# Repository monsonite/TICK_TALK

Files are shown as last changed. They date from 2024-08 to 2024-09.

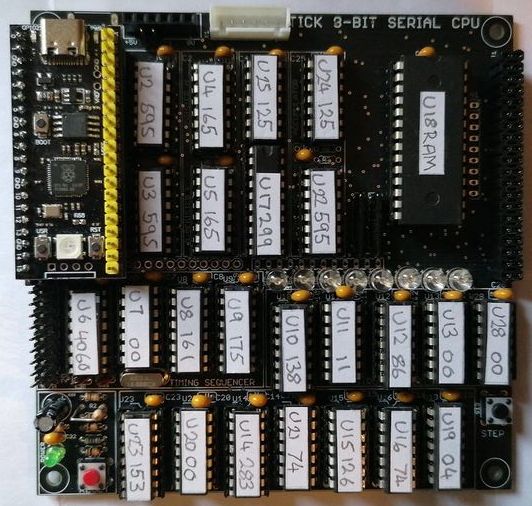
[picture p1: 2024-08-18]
Tick_Aug_17th.jpg

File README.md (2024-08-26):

# TICK_TALK
## An experimental 8-bit, bit serial computer.

## Hebden Bridge Workshop Update  25-08-24

OSHCamp 2024

TICK Workshop Update.

Thanks to the 16 people who attended the 1st TICK workshop session at Hebden Bridge, on Sunday August 25th.

Most kits were assembled without too many problems, and several were close to completion at the end of the afternoon.

Unfortunately some components were misplaced and not found until late in the afternoon, close to packing up time, but workarounds were employed.

Attendees should make contact me via email at k*n.boat@gmail.com - replacing the "t" with the 1st letter of my 1st name.

### Points Arising.

1.  The 74HC4060.dig file is now available. Download it and place it in the Lib  (libraries) folder of where you have installed "Digital"  - ideally under 

\Digital\Digital\lib\DIL Chips\74xx\counter

Then restart Digital and select components, custom, update and it should then be available.

2. Tick now has a Hackaday.io project page here:

https://hackaday.io/project/197333-tick-a-novel-homebrew-mcu-architecture-in-28-ics

Please feel free to join the project team and message me in the team messaging section.

3. It would be sensible to convert the Eagle CAD pcb schematic and pcb layout files to KiCad - to allow greater accessibility to interested users. I will investigate importing the schematic into Kicad, with the aim of generating the next iteration of the pcb using Kicad.

4. As the workshop was primarily focussed on assembly of the pcb in the time available, the Pi Pico firmware aspects of the project remained virtually unmentioned.

The principal role of the Pico is to emulate a 64K x16-bit ROM. It does this by "sniffing" the ROM address lines generated from the Program Counter, and using the two 74HC595 shift registers (U26, U27) located under the Pi Pico, to output the 16-bit value from that ROM address onto the Instruction Bus.

5. The 6-way JST cables supplied will allow the Pi Pico access to both the ROMulator Port X2 (on the left) and the SPI Port X1 (on the right). Details of these connectors and the modifications to the wiring of the cable to the Pico GPIO pins 18 to 21 and 26 to 29 will be released shortly in a separate document'

6.  I have received notification from PCBWay in China and they are prepared to sponsor the manufacture of the next version of the Tick PCB.

I am tempted to have a SMT version assembled in China - so it will be smaller, lighter and have better features.

I would like your feedback over, whether you would like to receive this SMT version in the Autumn.

Please send feedback to my Gmail address.

Ken

Update  - Lissa has created a new discord server for TICK

try this invite code.

https://discord.gg/FmW9dqFGb5

/*************************************************************************************************************************



TICK is an experimental 8-bit, serial arithmetic CPU designed around the commonly available 74HCxx logic series.

TICK uses 26 74HXxx ICs, plus a 32K byte RAM and a 64K x 16-bit ROM - or a ROM emulator.

TICK fits onto a 4-layer PCB, sized just 110mm x 110mm. It has 5 principal connectors that allow you to access all of the main signals and buses. Low cost 6-way JST XH ribbon cables are used to hook up the TICK serial interface bus and the Pi Pico SPI.  A 40 way 2.54mm pitch header allows access to the parallel buses.

USB (power) is supplied either through a USB microB connector or via USB C connector of the the Clone Pi Pico "ROMulator".

PCB Headers are included that will allow a very low-cost Raspberry Pi Pico (clone) to be plugged in, providing emulation of the ROM and also implementing a simple serial interface to a laptop or PC.

TICK has evolved slowly over several months, and this repo reflects the most recent design files, manufacturing data and BOM. The earlier repo "TICK" is purely reserved for earlier work. All current and future developments will be documented here.

TICK started life a few months ago and is highly influenced by the the developments I did on "MITE" its 16-bit Cousin. Here the basics of the timing pulse generator and ALU were thashed out to the point that I am happy to utilise them in a new design.

Much of the combinational logic has been rationalised, and short of implementing the ALU and control logic in a ROM, I believe that I have reached a point where the logic is stable, and not reduced to a blackbox ROM.

TICK is 26 74HCxx ICs plus a ROM and RAM.

The ICs are utilised in 5 main sub-circuits:

1. Clock Sequencer and Timing Pulse Generator.

2. Instruction Decoder

3. ALU and PC Incrementer, plus Jump logic.

4. Memory Control Hardware.

5. GPIO and ROMulator interfaces.

In an ideal world,  TICK would be a BlackBox with just 2 wires for power, and 2 wires for data in and data out. If you look at a landline telephone or broadband modem, they only have 2 wires or 4 wires. However for the purposes of this project we reqire syncronous data transfer - and that needs a clock that is shared between all nodes.

In general terms, TICK communicates with external devices via an SPI compatible interface.

## Architecture

TICK is highly influenced by Marcel van Kervinck's 8-bit Gigatron TTL Computer. The Gigatron used ten ICs in its ALU, I can do it serially in two. However a bit-serial design needs additional ICs to implement the clock sequencer, the timing pulse generator and the SRAM and Jump logic.

It is very marginal whether an 8-bit serial architecture will have fewer ICs than an 8-bit parallel design. Bit Serial really comes into fruition when you have a wordsize of 16 or more bits.

So the motivation for developing TICK was to make an intelligent node that can interface to SPI serial peripherals and other intelligent nodes. It won't be the fastest computer on the planet - but it should be able to compete with 1970s/80s 8-bit workhorses, like the 6502, Z80, 8051, 6309 etcand even older machines that predate the microprocessor - such as the  PDP-8 (1965) and the EDUC8 (1974).

TICK is a modified Harvard architecture.  Address and data from the ROM are conveyed on separate buses to those of the RAM. Simple shift registers are used to convert between the serial and parallel domains. A task that they can do very efficiently.

### Registers

TICK has a single 8-bit accumulator AC. AC may be loaded with an 8-bit literal direct from the lower 8 ROM data lines, or AC can be loaded with data addressed from the 32K x 8-bit SRAM.

As well as the Accumulator AC, TICK has a 16-bit wide general purpose register known as the B-Register. The B-Reg is 16-bits wide, in order to accept a 16-bit word, in parallel from the ROM and either use that as a indirect RAM address, or load it into the ROM Program Counter (PC) to perform a Conditional Branch or a 16-bit Long Jump.

The PC mentioned above is also 16-bits wide and can cover the full 16 bits of the ROM addressing range. A 16-bit jump is non-conditional, but an 8-bit "page" branch is conditional on the ZERO and SIGN flags from the Accumulator.

## Circuit Description (Draft 20-08-24)

Tick is an experimental, 8-bit, bit serial computer designed to interface to SPI peripherals and memory.

It has a 16-bit Program Counter, a 16-bit B-Register, an 8-bit Accumulator and an 8-bit Input Register.

The circuit may be subdivided into several sub-sections for easier analysis.

1. Clock Sequencer and Timing Pulse Generator (TPG)
2. Instruction Decoder
3. Program Counter (PC)
4. Arithmetic and Logic Unit (ALU)
5. Conditional Branch Logic
6. Memory Access
7. Input/Output  (I/O)
8. ROM Emulation

## 1. Clock Sequencer and Timing Pulse Generator (TPG)

This is at the heart of the design and co-ordinates all of the control signals.

A 14-bit binary counter U6 (74HC4060) provides a crystal oscillator with a 16MHz crystal Q1. This is divided down to provide 10, link selectable clock outputs from 1Khz (approx) to 1MHz. The selected clock feeds a 4-bit counter, U8 (74HC161) and this is used to generate a burst of 16 clock pulses for the Program Counter (PC-CLK) and 8 gated clock pulses (GCLK) for the 8-bit shift registers. A SR latch formed around NAND U7 (74HC00) with triple input AND U11 (74HC11) provides a means of gating the clock to generate PC-CLK and GCLK.

The terminal count of the 74HC161 (RCO) is used to feed a chain of 4, D-type flipflops U9 (74HC175), and these "top and tail" pulses T0, T1, T17 T18 and their complements are used to synchronise the loading of shift registers andread/write access to the SRAM.

A power-on reset circuit is formed around U19A and U19B. This resets all shift registers and counters when power is applied to the circuit. There is also a RESET switch S13, which allows a manual reset to be performed.

## 2. Instruction Decoder

The instruction from the ROM is 16-bits wide and consists od an instruction field IR7:0 and a data field P7:P0.

The instruction field is further divided into a 4-bit operand  IR7:IR4, and a condition field IR3:IR0.

If IR7=0, the remainder of the 16-bit word is treated as a literal and is loaded into the B-Register.

If IR7=1, this indicates a RAM memory reference instruction with IR6:4 defining the operation, and the remainder of the instruction word IR3:0 and P7:0 treated as a 12-bit address which is output onto the RAM address bus MA11:MA0.

Instruction decoding is done with 4 or 5 "basic gate" ICs. As entirely combinational logic, it could also be implemented in a small ROM, or even with a diode matrix.

Instruction decoding begins with U10 (74HC138) a 3 to 8 line decoder, which performs the primary stage of decoding. 

Here the instruction field IR6:4 is decoded into the 8 instruction groups, with one of its "Y" outputs being set low for each individual instruction group - as follows.

/Y0		LOAD
/Y1		AND
/Y2		XOR
/Y3		OR
/Y4		ADD
/Y5		SUB
/Y6		STORE
/Y7		JUMP

These low going outputs are further combined in logic U11, (74HC11), U12 (74HC86) and U13 (74HC00) to provide a series of control signals, time selected by the timing pulses T0, T1, T17 and T18.

Quad 2-input NAND gate U13 does the bulk of the secondary decoding, where instruction groups /Y0 to /Y7 are gated with timeslot pulses. 

The two XOR gates U12B and U12C have one input tied high and thus act as simple inverters. U12A is also an inverter and is connectedas an 8-input wired OR gate with 8 input diodes and a pull-down resistor, used to detect when the output of the Accumulator or memory on the data bus is equal to zero.

U11 is a triple 3-input AND. U11A detects if any of the Boolean instructions have been selected (/Y1, /Y2, /Y3) and is used to suppress the carry.

## 3. Program Counter.

This is a 16-bit counter and consists of two 74HC595 serial in parallel out (SIPO) shift registers U2 and U3 connected in series. As a bit serial computer, it is reasonable to use shift registers and a half adder to create a Program Counter, especially as it can be loaded from a serial data stream.

The registers convert a serial bitstream into a parallel address, which is used to address the 64K x 16-bit ROM (U1 AT27C1024). For development purposes, the ROM is replaced with a Pi Pico clone, for a more efficient development cycle.

The 74HC595 is a SIPO shift register, with all outputs connected to an octal tristate latch. Once the shift register contains the required address, this can then be latched onto the output pins, where it will remain for the whole duration of the machine cycle. In this respect, the PC "freezes" the address and as such acts as the Instruction Register, holding the Instruction for the complete Fetch, Execute, Writeback cycle. As the lower 12-bits of the ROM contain the effective memory address (EA), the address of the operand read, will be retained for the writeback operation.

A Program Counter has two modes of operation, either to increment the ROM address by 1 at the end of each machine cycle, or to load the shift registers from an external serial source to allow a jump to be executed. 

The PC increment hardware is based around a half adder, followed by a 2-input multiplexer. The mux chooses between the increment mode and the load (jump) mode.

The PC half adder is provided by one half of a 4-bit full adder (74HC283 U14). The multiplexer is one half of a 74HC126, quad tristate buffer (U15). The other halves of U14 and U15 are used in the ALU, so not wasted. Instruction group 7 "Jump" is used to swich the PC multiplexer between its +1 increment mode and the jump mode, where it is loaded with data from the B-Register, which has been loaded from the ROM or from and external source.

## 4. Arithmetic and Logic Unit (ALU)

The ALU is based around a full adder, in this case provided by U14 (74HC283) four bit adder that has been partitioned to provide a half adder for the Program Counter and a full adder for the ALU. The full adder can perform subtraction too, by inverting the input from the B-register and adding 1, by way of the Carry input.

The full adder provides sum (XOR) and carry (AND) outputs, which are selected using a 2-input multiplexer, provided by U15 (74HC126). This allows the ZERO, AND, XOR and OR bitwise Boolean logic functions to be selected by way of two instruction control lines I0 and I1. If a Boolean function is selected, the carry propagation from bit to bit is suppressed.

## 5. Conditional Branch Logic

During a conditional branch, the 4-bit instruction field IR3:0 defines the condition as follows by testing the ZERO flag and the MSB of the Accumulator:

0000		Long Jump
0001		AC > 0  	BGT
0010		AC < 0		BLT
0011		AC != 0		BNE
0100		AC = 0		BEQ
0101		AC >= 0		BGE
0110		AC <= 0		BLE
0111		Branch Always
1xxx		
  
A 4 input multiplexer, U23 (74HC153) receives the condition field IR2:0 on inputs C2:C0. The JUMP signal is used to enable the multiplexer via pin 1.

The ALU status bits ZERO and SIGN (BUS7), are applied to select inputs A and B. If a condition is met the BCC output on pin 7 is raised.

The other half of the multiplexer is not used.

The BCC output is combined in NAND U28 (74HC00) to provide a LONGJUMP control signal if IR3 = 0. If IR3 = 0 the jump address is taken from the 11 lower bits of the instruction word, limiting it to 0 to 2047 in RAM.

## 6. Memory Access.

The 32K byte RAM U18 (62256) is read onto the data bus during timeslot T0, and written back to during timeslot T18.

The address for the RAM comes from the full 16-bit output of the Instruction ROM but with the exception that IR7=1, so a range of 32768 addresses may be reached.

There are 2 distinct forms of Load instruction:

IR7=1 Memory Reference Instruction 

IR3:IR2 and P7:0 forms a 12-bit address for the A operand to place in the Accumulator. This applies to LOAD, AND, XOR, AND, ADD, SUB and STORE instructions.

IR7=0.

Load Accumulator with data from address IR7:0 and P7:0 thus covering addresses 0 to 32767, which is the full extent of the fitted RAM.

Load the B-Register with the 15 bit constant, IR6:0 and P7:0

## 7. Input/Output  (I/O)

TICK is intended to work with SPI peripherals and memory. As such it implements a basic SPI bus with MOSI, MISO, SCLK and /SS signals.

The serial output of the Accumulator U17 (74HC299) is fed through a tristate buffer U24A and sends this MOSI signal to connector X1 pin 2. The MISO signal is received by U22 (74HC595) 8-bit tristate, latchable shift register on X1 pin 3 and can be gated onto the 8-bit data bus. The serial clock X1 pin 4 is just the 8 cycle gated clock burst, GCLK. The slave select /SS or /CE (chip enable) is the inverted output Q4 of the gating counter U8 (74HC161). A maximum SCLK of 1MHz can be achieved from the current 16MHz clock crystal oscillator.

## 8. ROM Emulator and SPI Peripherals.

Whilst TICK was designed to have firmware coded into a 64K x 16-bit ROM, U1 (AT27C1024) it makes sense to emulate the ROM with a small microcontroller - in this case a low cost clone of the popular Raspberry Pi Pico module.

The Pico plugs into 2 x 20 way female pcb socket J3 on the left hand edge of the pcb.  It's GPIO lines 0 to 15, "sniff" the ROM address generated by the Program Counter, and then look up the associated instruction word from a table of ROM contents held in the flash memory of the Pico. This 16-bit word is then output to a pair of 74HC595 shift registers, U26 and U27 located below the Pico module, which present the "ROM" data to the relevant ROM data lines IR7:0 and P7:0.

The Pi Pico provides regulated 3V3 supply for the TICK board and also a USB serial port for debugging. Unused GPIO, ADC chanels and other resources on the Pico can be used to support the TICK board. The Pico can act as a smart serial peripheral and connect to the TICK via the SPI port connector X1.

Xpansion Ports, X1, X2 - Connector Pin-Outs

### X2  (left to right) ROMulator Port

Used to emulate a 64K x 16-bit ROM and provide serial port access to laptop.

1   3V3          Connects to VCC to power the Tick PCB

2   /PC_EN       Set low to eneable the Program counter

3   SER_IN       Serial data from Pi Pico to shift registers U26 and U27

4   SER_CLK      Clock from Pi Pico to synchronise the serial data packets and clock U26 and U27

5   STB          A strobe pulse at the end of the data packet that latches the data onto the Instruction Bus

6   0V           Connects to GND plane (0V) of Tick pcb

### X1  (left to right) SPI Port

Used to connect the Tick CPU to SPI peripherals or use the Pi Pico as a smart peripheral.

1   3V3          Connects to VCC to power the Tick PCB

2   MOSI         8-bit Serial data output from Tick Accumulator to PI Pico MISO

3   MISO         8-bit Serial data output from PI Pico MOSI to Tick input register U22 (74HC595).

4   GCLK         Gated clock burst generated by Tick to synchronise serial data transfer

5   /SS          Slave Select - signal goes low for the duration of the GCLK burst. Used to latch data into the SPI slave device

6   0V           Connects to GND plane (0V) of Tick pcb

Two 6-way JST cables are used to connect X1 and X2 to the GPIO and 3V3 supply from the Pi Pico. These need to have a couple of wires swapped  to form the following connections:

### X2 - ROMulator Port 

1       Pico 3V3

2       Pico 29  /PC_EN

3       Pico 28  Serial Data

4       Pico 27  Serial Clock

5       Pico 26  Latch data

6       Pico GND

### X1 - SPI Port 

1       Pico 3V3

2       Pico 19  Pico SPI 0 MISO

3       Pico 16  Pico SPI 0 MOSI

4       Pico 18  GCLK

5       Pico 17  /SS 

6       Pico GND

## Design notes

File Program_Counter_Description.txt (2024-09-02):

Program Counter.

The Program Counter consists of a 16-bit serial-in, parallel out shift register, a half adder, an 2-input multiplexer and a carry flipflop. However the design is somewhat convoluted and spread across 6 ICs.

The following notes explain the design, and a simulation of the Program Counter circuit is available on the github repo.

U2 and U3 (74HC595) form the 16-bit Program Counter.

Output pins

15		RMA15 (MSB)
1		RMA14
2		RMA13
3		RMA12
4		RMA11
5		RMA10
6		RMA9
7		RMA8  (LSB)

9		Serial Output to lower stage
10		/CLR	Active LOW reset signal - check it goes low when RESET switch pressed
11		PC_CLK  16-clock pulse burst - check for continuous clocking
12		Outout Latch clock pulse - low going pulse, every 16th clock
13      /PC_EN  Active LOW enable pin - should remain LOW
14      PC_IN  Serial Input 

8		GND
16 		3V3

The Program Counter is connected to U12, U14 U15 and U16.

U12 (74HC86) provides inversion of the !JMP signal.

The left hand side of U14 (74HC283) provides a half adder to increment the PC by one, once per machine cycle (20 clocks).

The right hand side of  U15 (74HC126) provides a 2-input multiplexer. The PC is either loaded with the current count, or if !JMP is LOW it is loaded with the value in the B-Register.

U16 (74HC74) is a dual flipflop. The right-hand flipflop is used to hold any carry produced when adding 1 to the PC and adding it into the next half sum.

Ensure continuity of:

U2 (14) to U15 (8,11) 	*
U2 (9) to U3 (14)  		*
U3 (9) to U14(6) 		*

U16 (12) to U14(1)		*
U16 (11) to U7 (8)		new
U16 (10) to U9(11)		new
U16 (9) to U14(7)		*
 
U14 (4) to U15(9)		*

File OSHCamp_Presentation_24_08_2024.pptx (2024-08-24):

## Revisiting the Bit-Serial Computer Architecture

A Practical Guide to Bit Serial Computing

Ken Boak
OSHCamp, 24th August 2024

## Introduction

In the late 1980s, the late, great author and futurologist, Richard Adams made a series of radio documentaries, and a book “Last Chance to See” documenting his travels around the world to seek out and document various animal species that were on the brink of extinction, including the Komodo Dragon, the Kakapo of New Zealand and the Aye-Aye lemur of Madagascar.

In a lesser capacity, I have spent the last 5 years exploring simple computer architectures, based on what are often colloquially known as “TTL” chips, but more correctly 74HC series of logic devices.
With successive generations of logic, these devices have 60+ years or heritage, and are based on high-speed CMOS logic, FETs and transmission gates, and no longer bipolar, multi-emitter transistors, but have retained their pin compatibility with the older series.

However, these devices are slowly being obsoleted, resulting in a smaller range, fewer packaging options and decreased availability. Basically the slow erosion and ultimate extinction of the species.

I realised that the window of opportunity to build a working “TTL Computer” was rapidly diminishing, and so after 4 years of procrastination, I began my journey, for proper, earlier this year.
To add a little novelty to my design, I chose to use the little known technique of Bit Serial Arithmetic.

## Until 1960, almost all computers used bit-serial arithmetic

- Uses considerably fewer vacuum tubes or transistors than parallel
- It only had to process a pair of bits at a time
- It simplified hardware making it practical and mostly affordable
- Easily extended to longer word sizes with no linear scaling in hardware
- The trade off, was it was relatively slow. EDSAC (1949) managed 600 operations per second, on 17-bit words.
- With 74HCxx logic we can achieve 50,000 8-bit additions per second.

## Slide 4

- In this presentation I will discuss the techniques and practical hardware required for bit-serial computation.
- Commencing with the basic full adder circuit, I show how it is applied to bit serial addition and subtraction and then extend it to provide the common logic functions AND, OR, XOR and ZERO. It may also provide one’s complement invertion, and two’s complement negation. Increment and Decrement are also possible with simple extensions to the control of the ALU.
- As well as the ALU, shift registers are the fundamental storage device for bit-serial computer architectures. I summarise the basic types, their function and use and give examples available cheaply in 74HCxx High Speed series logic.
- Shift registers can also perform operations such as shift, rotate and nybble or byte swap.
- The discussion concludes with an illustration of how a small, experimental 8-bit, bit-serial computer can be built up from common 74HC series parts.
- This is the theme of tomorrow’s Workshop Build session: your own bit-serial machine.

## 1 plus 1 is 10……. 1 and 1 is 1 ……..

- The principle is very simple – it’s just like basic addition that we all learned in primary school, except that it is in binary.
- We start with the units on the right, and if there is a carry, we make a mental note and bring it to the next column to the left.
- For binary, the process is almost identical. Starting with the least significant bits, A0 and B0, we add them together. If a carry is generated, we store it in a flipflop so that it can be added into the next addition, A1 plus B1.
- We repeat this bit operation until we have completed the whole word.
- To do this in logic we need a pair of shift registers to feed the serialised data into a full adder. The full adder produces the SUM term from A XOR B and carry from the A AND B function. This produces a half add, which is then repeated to include any carry input from the previous stage.
- In total we require just two XOR gates and 3 NAND gates, plus a flipflop to hold the inter-stage carry.

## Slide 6

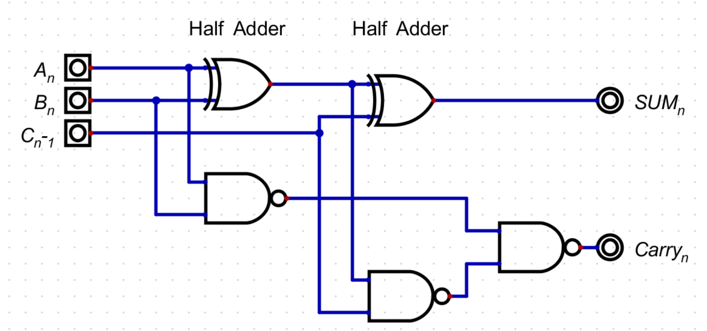
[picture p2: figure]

A Full Adder made from basic gates.

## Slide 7

A typical serial adder.

It uses two shift registers A3:A0 and B3:B0. Shift register A is normally called the Accumulator. It can be parallel loaded from a bus, or serially loaded via register B.

Note how the least significant bits A0 and B0 are processed first!
The full adder FA, generates the Sum and Carry terms of the applied bits. The sum is recirculated back to the A shift register.
Any carry generated is stored in a D-type flipflop and fed to the Carry Input Cin, so that it can be included in the next cycle.

The cycle repeats until all n-bits have been processed, and all bits are stored in the Accumulator – in the position of their correct binary weighting.

This basic design is easily modified for subtraction and other logical functions.

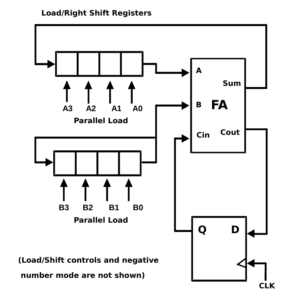
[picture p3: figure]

## The Arithmetic and Logic Unit ALU

- The ALU provides addition, subtraction and 3 logic functions AND, OR and XOR. It also can generate zero, which is good for clearing the accumulator.
- It operates on A and B inputs, one bit at a time – plus any carry that was generated from the previous bit operation.
- Carry is suppressed when we perform logical operations.
- It is based around a full adder which generates Sum and Carry outputs.
- As the sum is the XOR of the inputs and the Carry is AND, we get these logic functions almost for free. We use a multiplexer to select either the XOR or the AND function.
- Using 74HCxx basic gates the ALU is just 5 ICs – regardless of the length of the word to be processed.
- Because of its compactness, the ALU could be programmed into a small ROM (256 bytes) to replace the combinational logic of XOR and NAND gates

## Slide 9

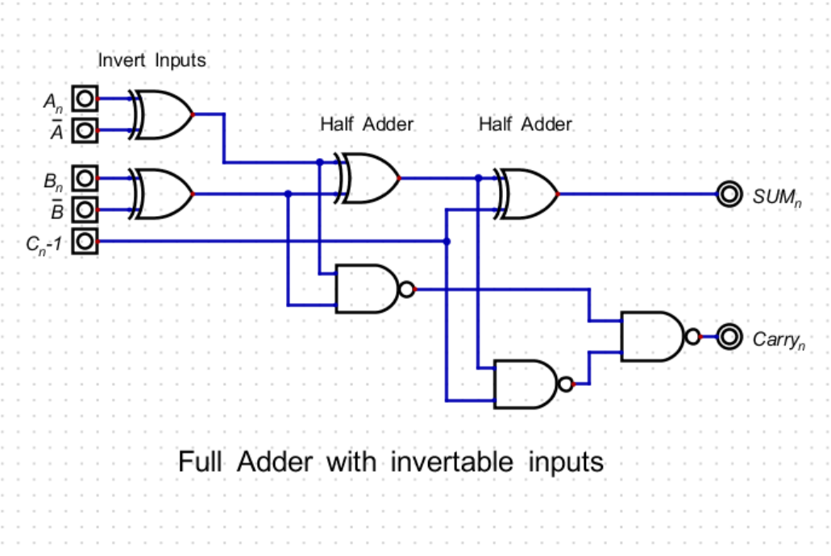
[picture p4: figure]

The ALU design commences with a full adder, (made from 2 half adders) with its inputs invertible, using a pair of XOR gates. It produces the two terms, Sum and Carry, which are the XOR and the AND functions of its inputs.

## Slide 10

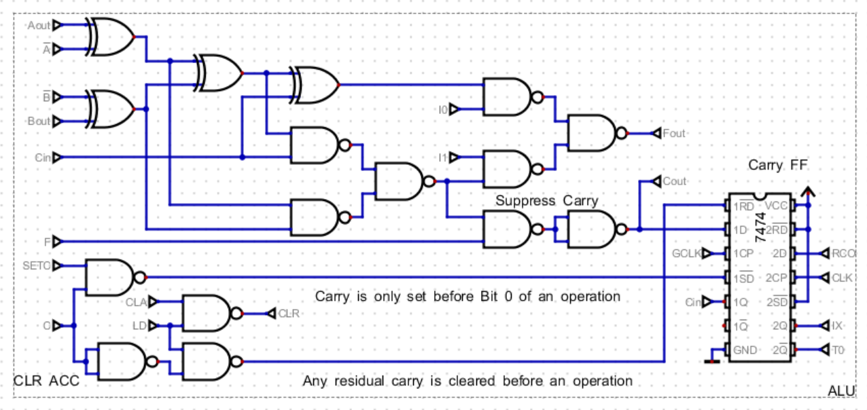
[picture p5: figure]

- The Full Adder is extended with multiplexer output (I0 and I1) to select between the SUM function (XOR) and the Carry function (AND). This mux will also produce the ZERO and OR functions.
- Note carry suppress logic controlled by input F for Boolean opeartions, and carry D-type flipflop.
- 7 control signals define which instruction is selected and control the Carry logic.

## Shift Registers - Demystified

- Shift registers are a fundamental building block of serial arithmetic.
- Essentially just a chain of D-type flipflops, with some surrounding support logic.
- Widely forgotten or misunderstood by current generation of engineers and hobbyists.
- 5 or 6 types available in 74HCxx logic. Available in 4, 8, 64(dual) bits in length.
- Serial In – Parallel Out (SIPO) 74HC164 (8-bit)
- Parallel In – Serial Out (PISO) 74HC165 (8-bit)
- Serial In – Latched Parallel Out (Tristate) 74HC595 (8-bit)
- Universal, Bidirectional, Parallel In/Out (tristate), 8-bit Serial In/Out 74HC299
- Serial In – Serial Out CD4517 (Dual 64-bit with taps every 16-bits)
- Up to 64 or 128 stages in length. CD4517 is dual 64-bit, CD4557 is 1 to 64 bit
- They provide the interface between the parallel and serial domains and allow communication of data via a 4 wire interface at clock speeds of about 20MHz.

## Program Counter – Using Shift Registers

- Frequently a Program Counter would be made from a binary counter, often using 4-bit presettable counters like the 74HC161.
- In a bit serial design the program counter runs at the machine cycle rate – updating every 20 clock pulses.
- In the proposed design the program counter is made from a pair of 74HC595 shift registers and a half- adder to add 1 on each machine cycle.
- When a jump is performed, a multiplexer allows the PC to be loaded with a jump address from the B-register or other serial data source.

## Timing and Control

- We have to co-ordinate the action of the shift registers with a series of Timing, State and clock pulses.
- Timing pulses, T0 to Tn are used to initiate the loading and reading of the shift registers.
- A gated clock GCLK, of n pulses, ensures that n-bits are correctly transferred between registers.
- The machine has certain states: instruction fetch, decode, operand fetch, execute, write-back results to memory and increment the Program Counter.
- Certain operations can be completed in parallel with one another.

## Instruction Decoding

- The instruction is held in ROM as a 16-bit word.
- It consists of a 4-bit instruction field and a 12-bit address/data field.
- There are 8 instruction groups: LOAD, AND, XOR, OR, ADD, SUB, STORE and JUMP.
- The instruction group is decoded using a 74HC138, a 3 to 8 line decoder.
- Futher combinational logic combines (gates) the instruction group, with certain timing pulses to generate the various control signals for the machine.
- Each instruction takes 20 clock cycles to perform. This 20 clock machine cycle consists of 16 clock cycles needed to increment the serial Program Counter, plus a pair of “top and tail” pulses at each end of the PC clock burst.
- Instructions operate on the current contents of the Accumulator and a byte from a 12-bit memory address or an 8-bit literal or constant from ROM that is fed to the ALU via the B-Register.

## Shift Registers are Key to SPI Serial Communication

- The intention is to make a simple bit serial computer which can communicate with memory and other peripherals, such as sensors, I/O expanders over SPI (Serial Peripheral Interface – Motorola c.1983)
- The machine has a 6-pin socket that conveys the necessary serial data streams, clocking and power and ground. This equires a minimum of 4 wires between Master and Slave: frequently called MOSI, MISO, SCLK and /CE (/SS).
- A word is transferred from Master to Slave, whilst simultaneously the Slave transfers a word back to the Master.
- This can be easily done using a pair of 74HC299 universal shift registers
- Easy to implement and economical in pcb traces
- Additionally, a parallel 8-bit bus which essentially replicates the SRAM data and address buses on a female pcb connector may be used for further parallel expansion.

## Serial Memory

- Serial memory was originally implemented as serial delay lines (e.g. mercury acoustic delay lines used in EDSAC 1949), electrostatic storage of charge in the phosphor of a CRT tube or a rotating magnetic drum with multiple heads.
- Disks and magnetic drums are fundamentally serial devices
- Serial EEPROM, Flash FRAM and SRAM appeared in the mid-1990s
- Low cost, 8-pin packages and relatively easy to use, with SPI and an industry standard package and instruction set.

## “TICK” – A Bit Serial SBC for Experimentation

- Combines a versatile ALU with examples of some of the common shift register types. 74HC165, 74HC595, 74HC299
- 8-bit, bit serial arithmetic, ADD, SUB, AND, XOR, OR
- 32K bytes of SRAM
- Direct interface to SPI with MOSI, MISO and GCLK
- Entirely through hole components for simplified construction
- Raspberry Pi Pico clone provides user interface, ROM emulation, GPIO and debugging
- Link selectable clock frequency from 1kHz to 1MHz
- Single stepping and debug to laptop
- 8 LEDs to show Accumulator contents
- Affordable – about £20 on 110x110 mm pcb from JLC PCB

## Part 1- A Brief Introduction to Shift Registers

- Here I present four common types of shift register. They will be used together to build the first stage of the processor – a bit serial adder. This adder will ;ater be augmented with more ICs, to extend it to a fully capable ALU.
- The first shift register is a 74HC164, an 8-bit serial input, parallel output device, in a compact 14-pin package. It can be clocked at approaching 80MHz.
- The complementary part is the 74HC165 which is an 8-bit parallel input, serial output part. It has a greater than 50MHz maximum clock frequency at 5V
- The third device is the 74HC595, which is similar to the 74HC164, but incorporates an 8-bit tristate output, parallel register. This makes it compatible with parallel-bus oriented systems. Some manufacturer’s 74HC595s will clock at 90 to 110MHz.

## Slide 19

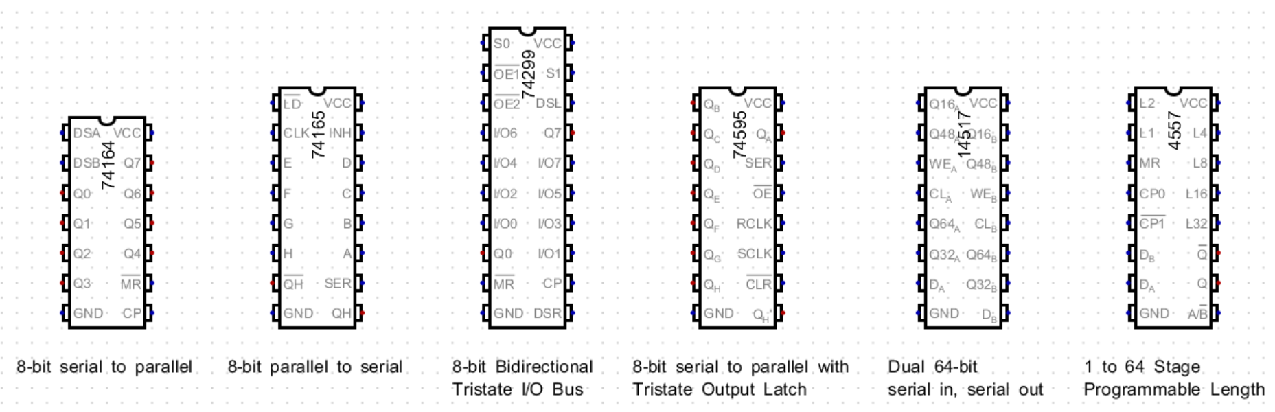
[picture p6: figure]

Common types of shift register in 74HCxx and 4xxx series CMOS Logic

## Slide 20

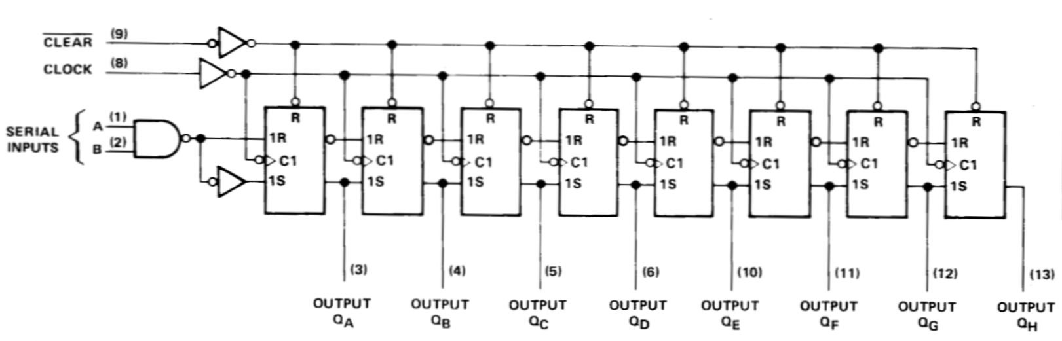
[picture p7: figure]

- 74HC164 8-bit SIPO shift register
- Simplest of all shift register devices
- Used to convert serial data into parallel
- Note – outputs will change with every clock pulse – so only read at end of clock sequence
- Compact 14-pin DIL package

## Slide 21

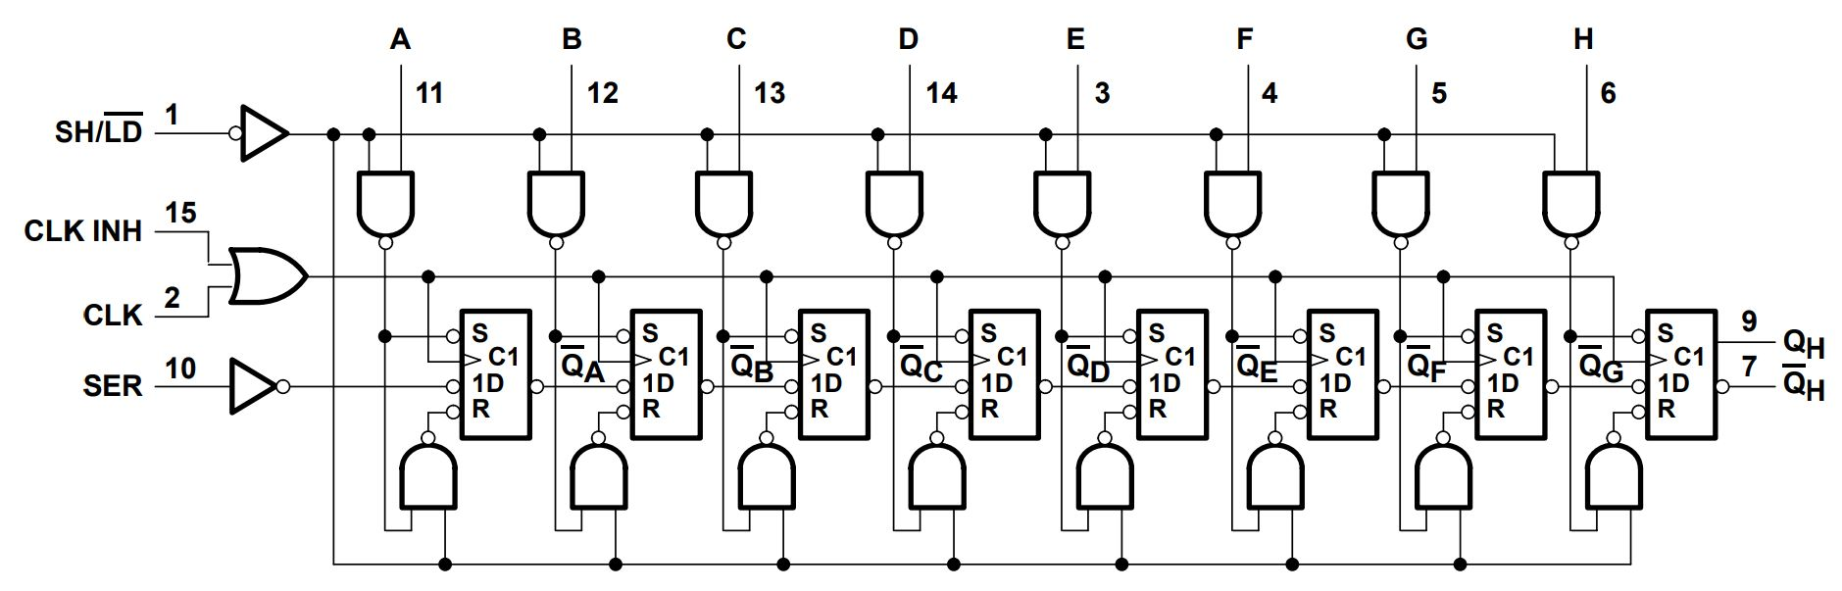
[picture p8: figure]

- 74HC165 8-bit PISO shift register
- Used for inputing data from parallel bus and converting to series bit stream
- Often used to read switch matrices or extending number of input ports
- 16 pin DIL package

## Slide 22

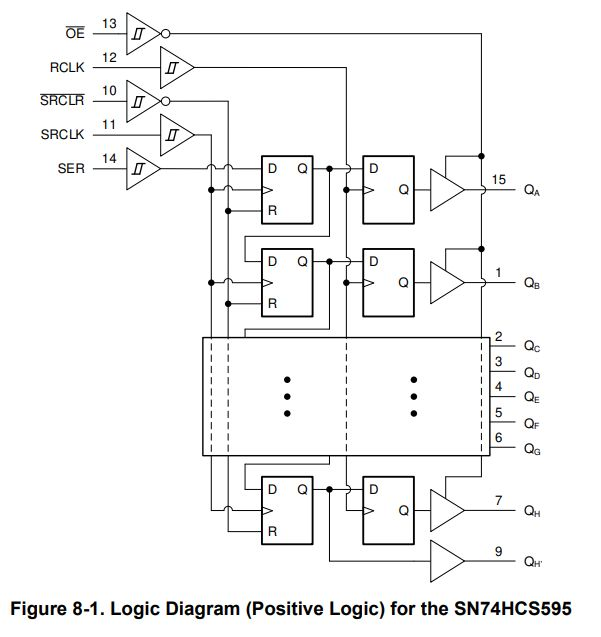
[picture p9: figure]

- 74HC595 8-bit SIPO shift register with parallel, tristate D-type output latch.
- Often used for GPIO extension and bus based systems
- Separate clocks for serial shift register and parallel latch
- 16 pin DIL package

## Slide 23

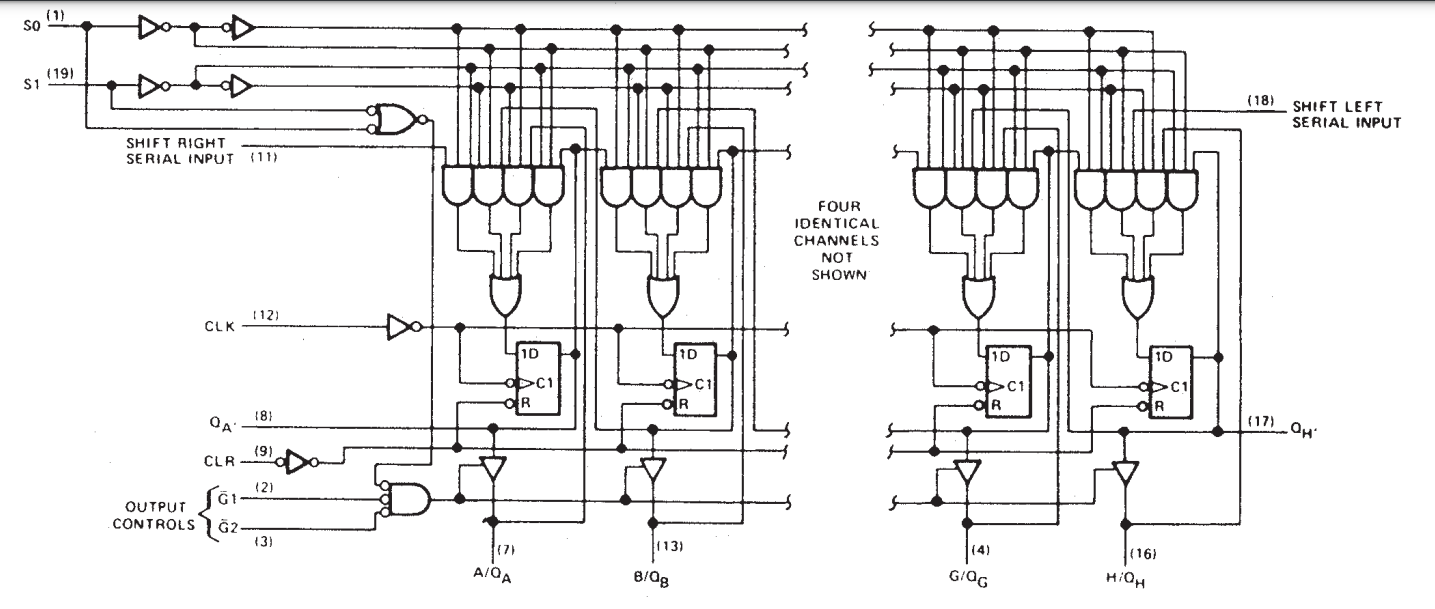
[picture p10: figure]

- 74HC299 Universal, bidirectional 8-bit shift register with with tristate parallel I/0 bus
- Ideal to interface to parallel bus systems
- Note extensive use of “steering” logic.
- 20 DIL pin package

## The Clock Sequencer

- Timing is very important in any digital circuit.  The clock sequencer and timing pulse generator (TPG) co-ordinates all of the control signals.
- The timing pulses trigger an SR flip-flop and generate a clock gating pulse, which is used to generate a sequence of 16 clock pulses, plus two “top and tail” pulses.

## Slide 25

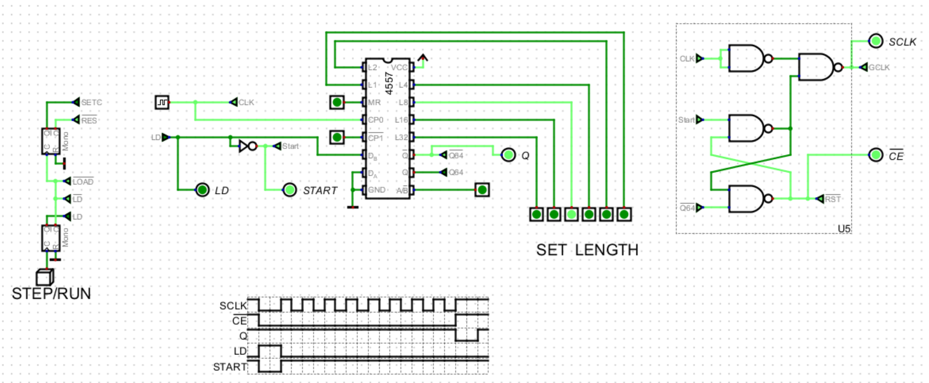
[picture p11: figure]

The SR Latch generates the !CE signal and gates the system clock to produce a train of 8-clock pulses, in this example.

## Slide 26

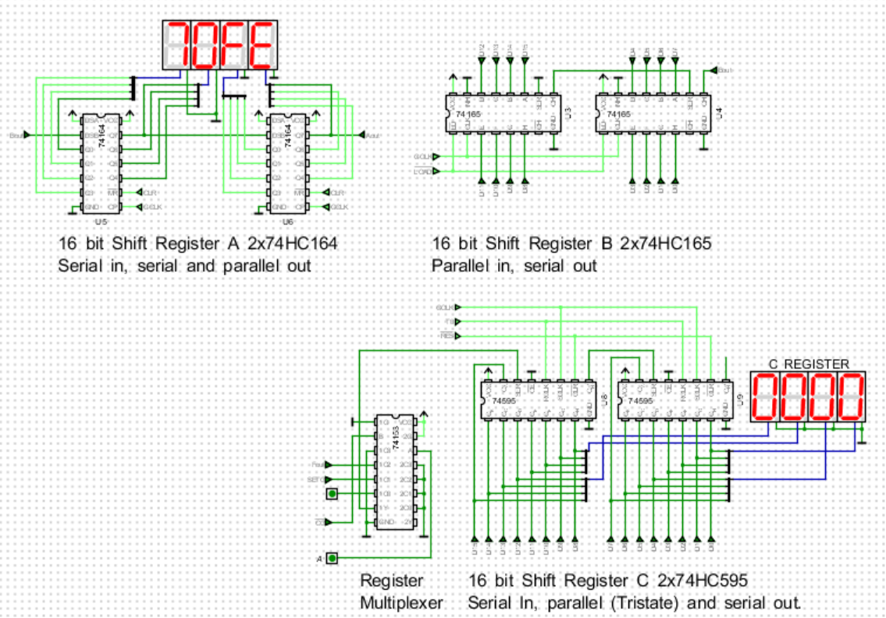
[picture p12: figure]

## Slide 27

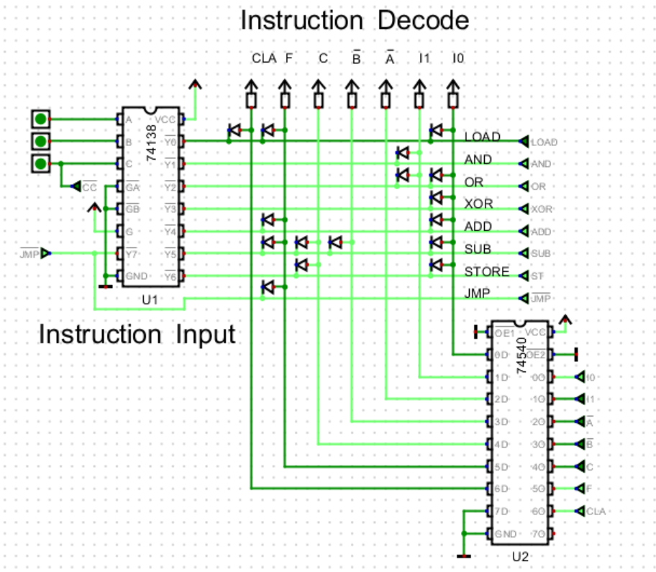
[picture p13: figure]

A 3 bit instruction is applied to the 74HC138, 3 to 8-line decoder on the left.
One of its outputs goes low and this is decoded into 8-control signals by the diode array. A 74HC540 inverter/driver buffers the output signal

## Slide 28

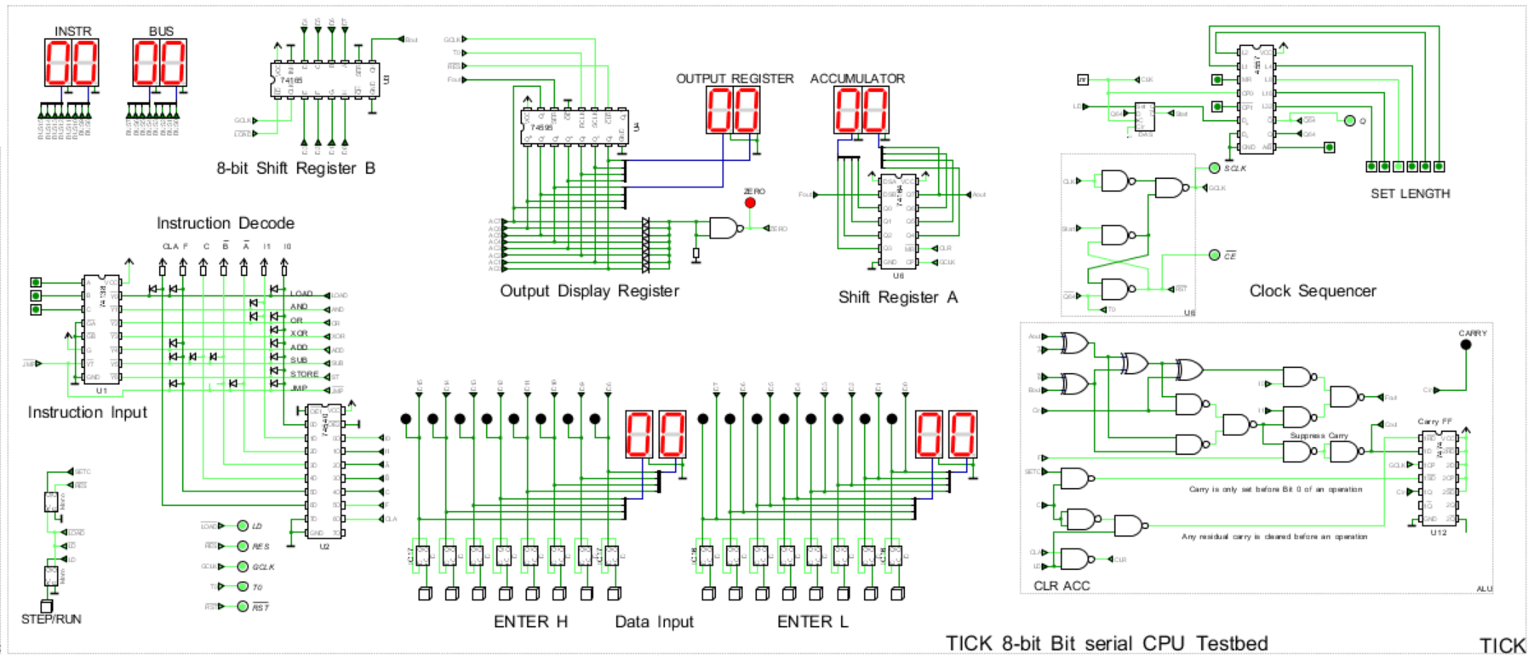
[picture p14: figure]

The various system elements are combined to make a simple 8-bit processor.
For workshop purposes, The instruction decoder and data entry inputs, and display of results will be handled using an Arduino NANO. This reduces the total package count to about 12 parts, whilst experimenting, flexibly with longer shift registers.

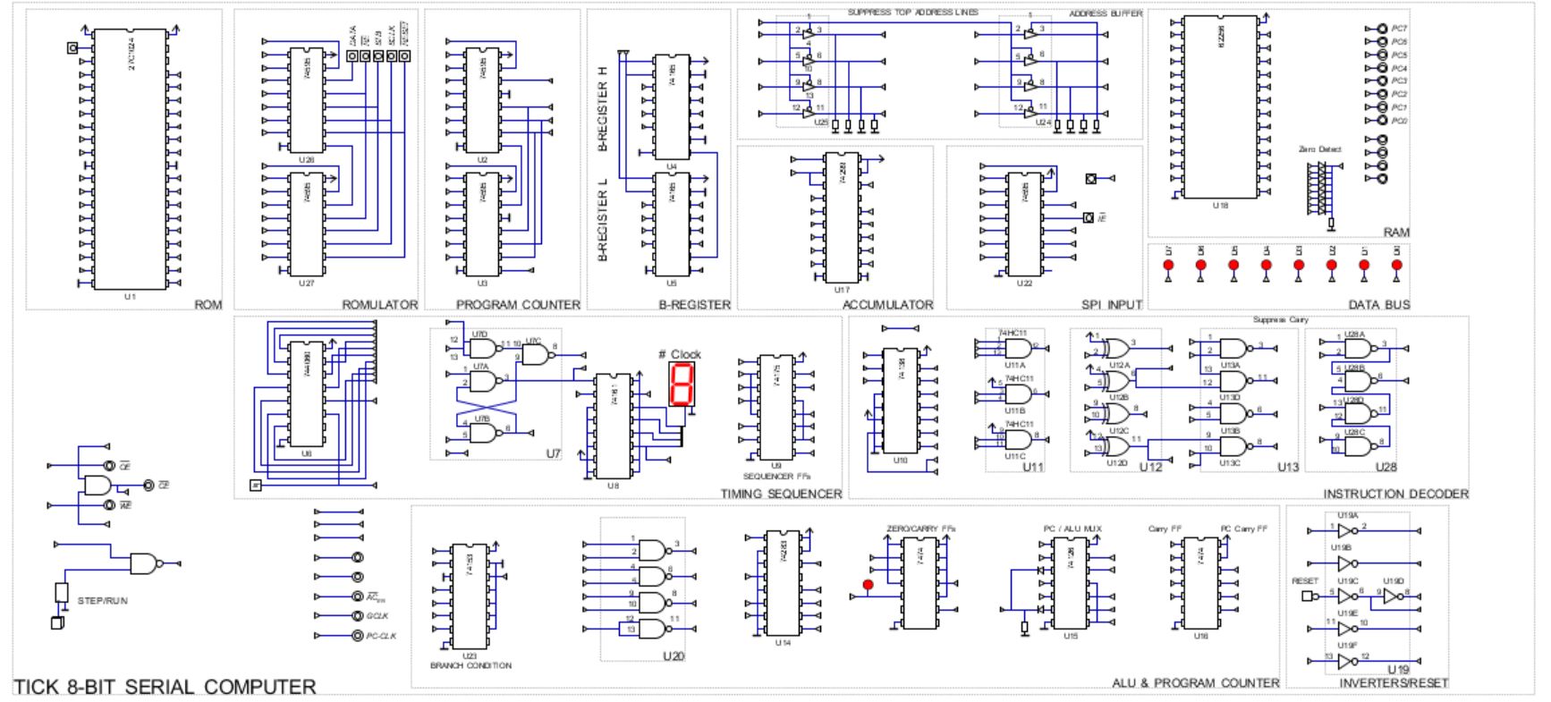
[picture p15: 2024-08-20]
TICK_schematic.jpg

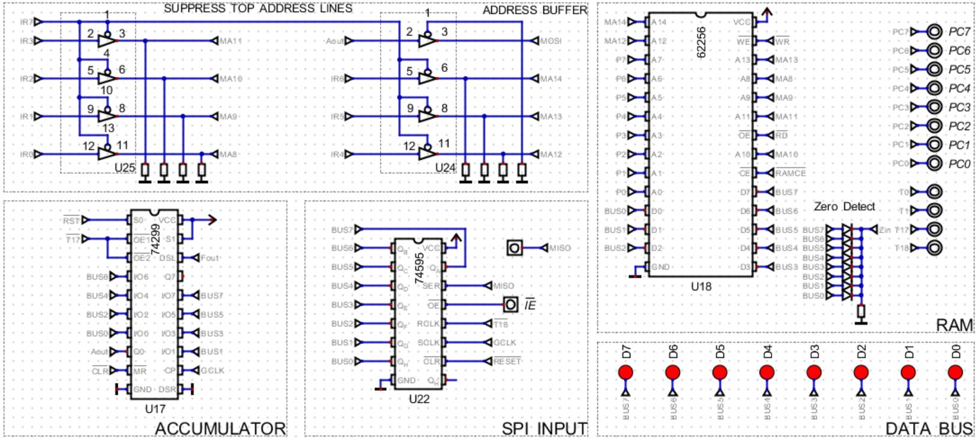
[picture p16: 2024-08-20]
Accumulator_SPI_RAM_Buffers_schematic.jpg

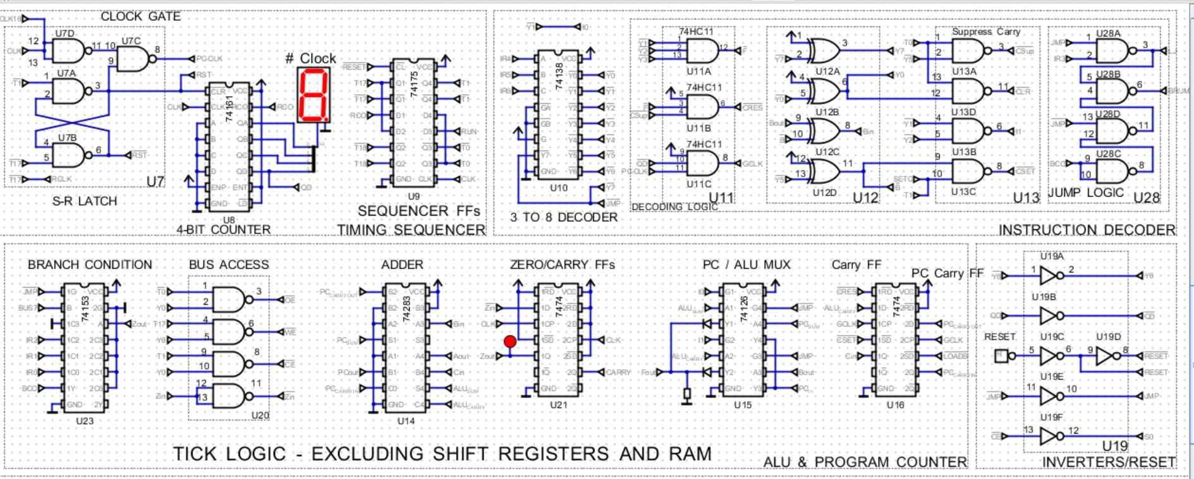
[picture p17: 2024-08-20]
TICK_LOGIC_Schematic.jpg

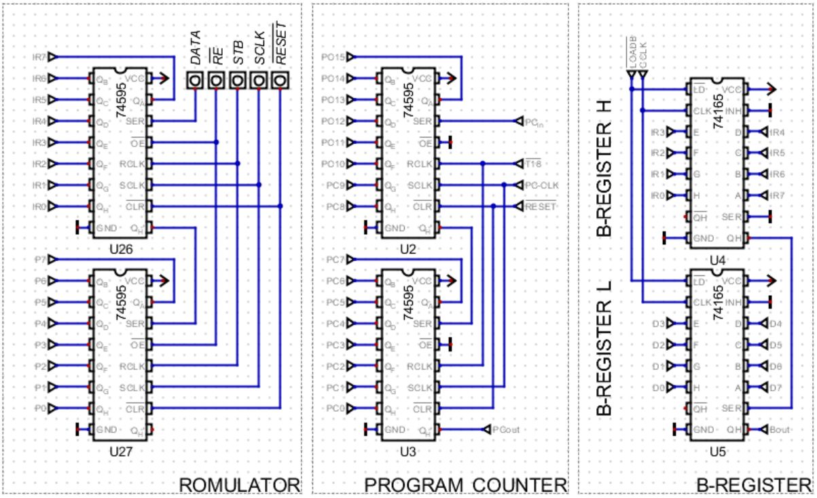
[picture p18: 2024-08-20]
ROMulator_PC_B-Reg_schematic.jpg

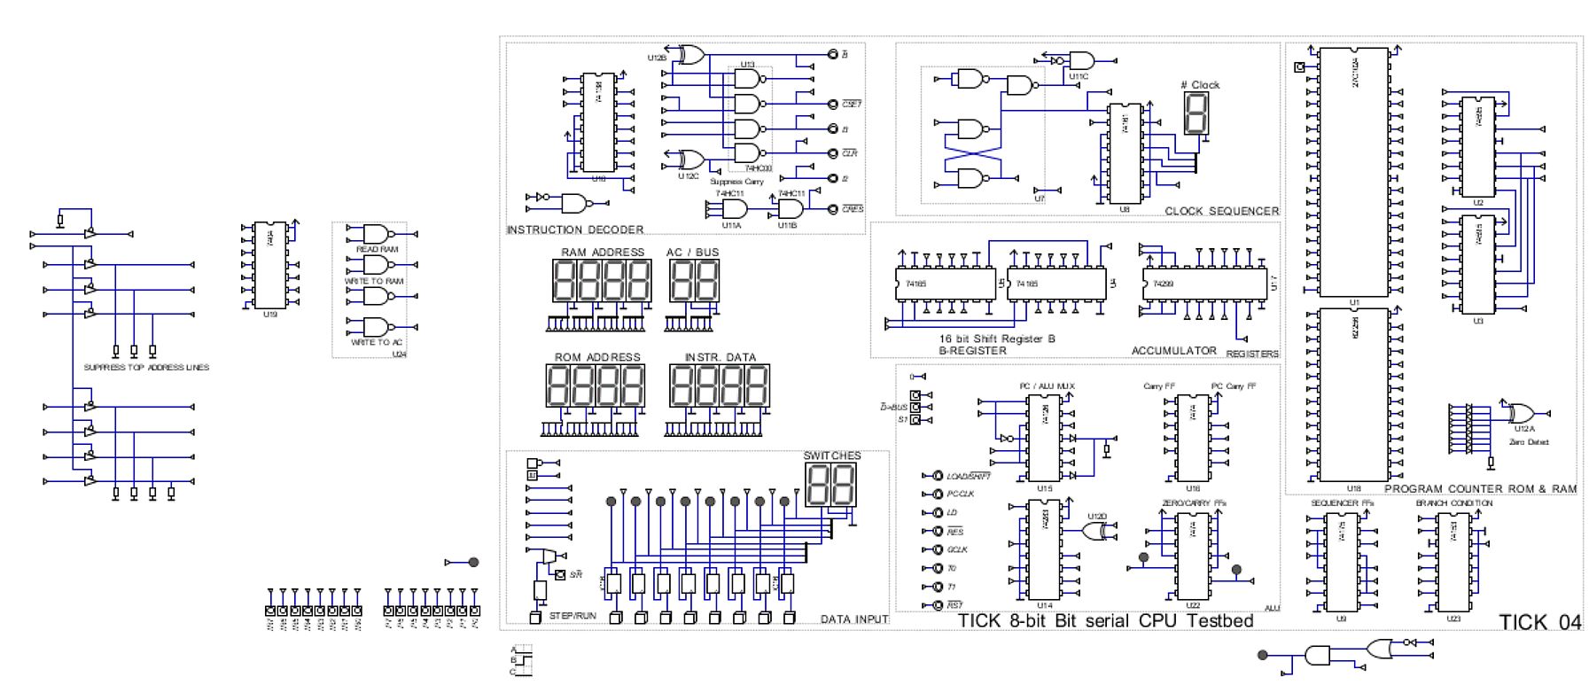
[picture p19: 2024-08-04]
TICK_simulation_schematic.jpg

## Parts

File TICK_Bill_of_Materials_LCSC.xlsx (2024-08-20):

 | Throughhole |  |  | LCSC Part
ID | Type | Description | Function
U2 | 74HC595 | Serial 8-bit Shift Register with latch | Program Counter | C507175
U3 | 74HC595 | Serial 8-bit Shift Register with latch | Program Counter | C507175
U4 | 74HC165 | Parallel Load 8-bit shift register | B Register | C507183
U5 | 74HC165 | Parallel Load 8-bit shift register | B Register | C507183
U6 | 74HC4060 | 14 stage binary counter/ crystal os. | Clock generator | Mouser
U7 | 74HC00 | Quad 2-input NAND | SR gate | C22436639
U8 | 74HC161 | 4-bit presettable counter | Clock Sequencer | C22436659
U9 | 74HC175 | Quad flipflops | Timing sequencer | Mouser
U10 | 74HC138 | 3 to 8 line decoder | Instruction Decoder | C22436652
U11 | 74HC11 | Triple 3 input AND | Instruction decoder | C22436648
U12 | 74HC86 | Quad 2-input XOR | Instruction Decoder | C18723533
U13 | 74HC00 | Quad 2-input NAND | Instruction Decoder | C22436639
U14 | 74HC283 | 4-bit adder | ALU and OC | C24833608
U15 | 74HC126 | quad tristate buffer | ALU/PC mux | C32710642
U16 | 74HC74 | Dual edge trigerred D type flip flop | Carry Flipflop | C22436663
U17 | 74HC299 | 8-bit universal shift register | Accumulator | Mouser
U18 | CY62C256 | 32Kx8 SRAM | RAM | Mouser
U19 | 74HC04 | Hex Inverter | various | C18723507
U20 | 74HC00 | Quad 2-input NAND | Instruction Decoder | C22436639
U21 | 74HC74 | Dual edge trigerred D type flip flop | Carry Flipflop | C22436663
U22 | 74HC595 | Serial 8-bit Shift Register with latch | Serial Input | C507175
U23 | 74HC153 | Dual 4:1 multiplexer | Condition detector | C18723507
U24 | 74HC125 | Quad tristate buffer (inverted enable) | Address Suppress | C2890
U25 | 74HC125 | Quad tristate buffer (inverted enable) | Address Suppress | C2890
U26 | 74HC595 | Serial 8-bit Shift Register with latch | ROMulator | C507175
U27 | 74HC595 | Serial 8-bit Shift Register with latch | ROMulator | C507175
U28 | 74HC00 | Quad 2-input NAND | Instruction Decoder | C22436639
R1, R7 | 100R 125mW
R2 | 10M 125mW
R3, R4, R5, R6,R8, R9 | 10K 125mW
RN1 | 10K x 8 | Resistor network 8 resistors common
RN2 | 470R x 4 | Resistor network 4 resistors common
RN3 | 470R x 4 | Resistor network 4 resistors common
C1-C28, C32 | 100nF 2.54mm | 100nF decoupling capacitors
C30,C31 | 22pF 2.54mm | Crystal osc tank capacitors
Q1 |  | 16MHz HC 49 crystal
J1/J2, J3 |  | 2 x 20pin PCB female socket
J4 |  | 1 x 20 pin PCD female socket
X1, X2 |  | JST XH 6-pin header
S12,S13 |  | 6mm x 6mm tact switch
PCB 1 |  | PCB 4-layer 110mm x 110mm

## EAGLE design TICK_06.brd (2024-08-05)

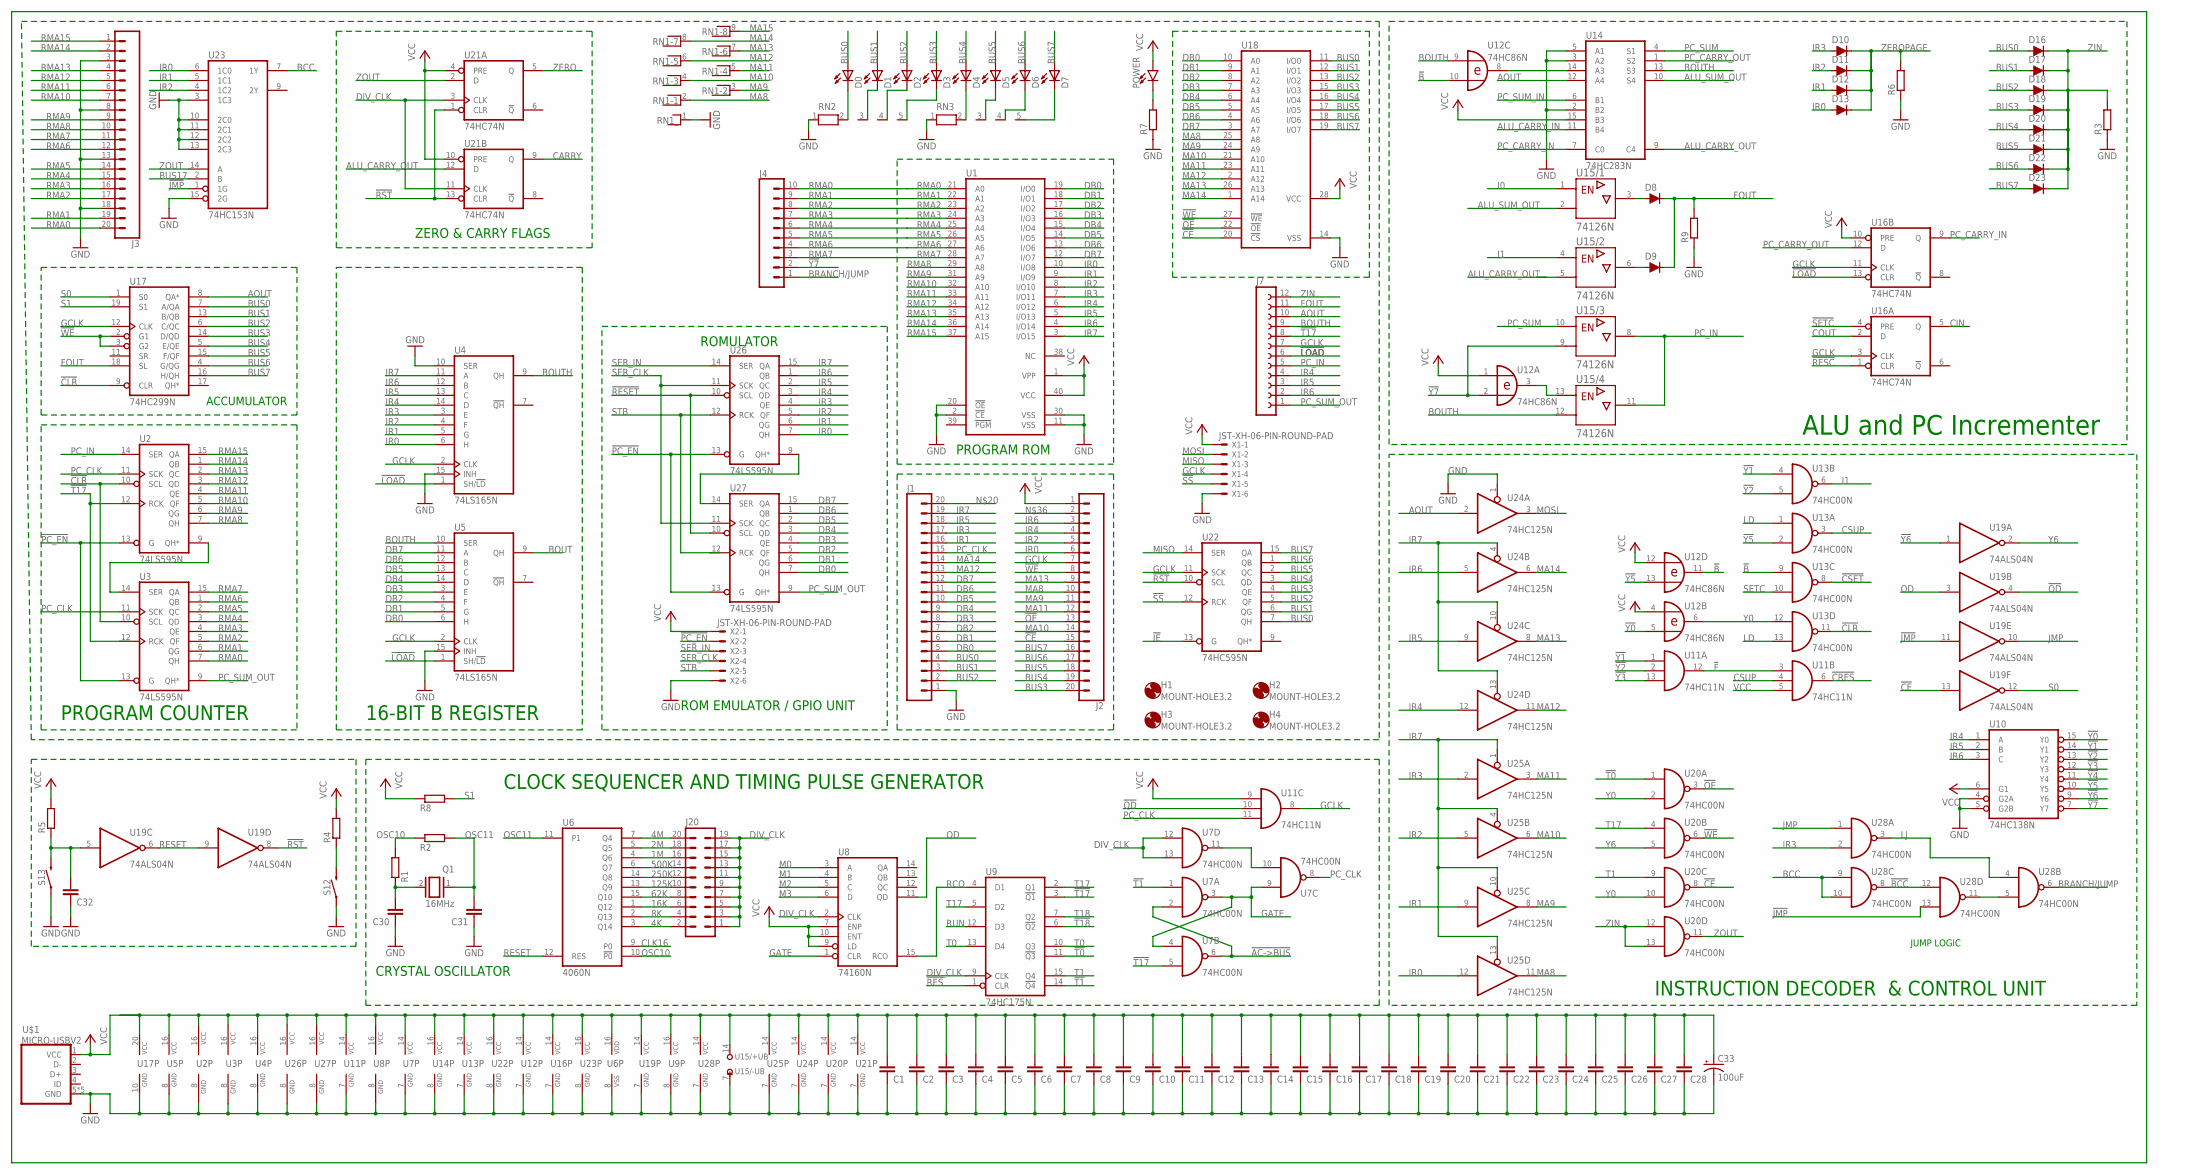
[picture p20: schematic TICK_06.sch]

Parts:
C1, C2, C3, C4, C5, C6, C7, C8, C9, C10, C11, C12, C13, C14, C15, C16, C17, C18, C19, C20, C21, C22, C23, C24, C25, C26, C27, C28, C30, C31, C32: C-EU025-024X044; C025-024X044
C33: 100uF; CPOL-RADIAL-2.5MM-6.5MM
D0, D1, D2, D3, D4, D5, D6, D7: LED3MM
D8, D9, D10, D11, D12, D13, D17, D18, D19, D20, D21, D22, D23: 200mA/100V/1V; DIODE-1N4148
D16: 200mA/100V/1V; DIODE-1N4148-KIT
H1, H2, H3, H4: MOUNT-HOLE3.2; 3,2
J1, J2, J3: CONN_20NO_SILK_KIT; 1X20_NO_SILK_KIT
J4: CONN_10"; 1X10
J7: FE12-1; FE12
J20: MA10-2
POWER: LED3MM; LED_3MM
Q1: 16MHz; QS
R1, R2, R3, R4, R5, R6, R7, R8, R9: R-EU_0204/5; 0204/5
RN1: RNX8; RN-9
RN2, RN3: RN04; RN-5
S12, S13: MOMENTARY-SWITCH-SPST-PTH-6.0MM; TACTILE_SWITCH_PTH_6.0MM
U1: 27C1024HG; DIL40
U2, U3, U26, U27: 74LS595N; DIL16
U4, U5: 74LS165N; DIL16
U6: 4060N; DIL16
U7, U13, U20, U28: 74HC00N; DIL14
U8: 74160N; DIL16
U9: 74HC175N; DIL16
U10: 74HC138N; DIL16
U11: 74HC11N; DIL14
U12: 74HC86N; DIL14
U14: 74HC283N; DIL16
U15: 74126N; DIL14
U16, U21: 74HC74N; DIL14
U17: 74HC299N; DIL20
U18: 62256P; DIL28-6
U19: 74ALS04N; DIL14
U22: 74HC595N; DIL16
U23: 74HC153N; DIL16
U24, U25: 74HC125N; DIL14
U$1: MICRO-USBV2; MICRO-USB-2
X1, X2: JST-XH-06-PIN-ROUND-PAD; JST-XH-06-PACKAGE-ROUND-PAD

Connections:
1M: J20.16, U6.4 (Q6)
2M: J20.18, U6.5 (Q5)
4K: J20.2, U6.3 (Q14)
4M: J20.20, U6.7 (Q4)
8K: J20.4, U6.2 (Q13)
16K: J20.6, U6.1 (Q12)
62K: J20.8, U6.15 (Q10)
125K: J20.10, U6.13 (Q9)
250K: J20.12, U6.14 (Q8)
500K: J20.14, U6.6 (Q7)
!AC->BUS: U7.2 (I1), U7.6 (O)
!B: U12.10 (I1), U12.11 (O), U13.9 (I0)
!BCC: U28.8 (O), U28.12 (I0)
!CE: J2.15, U18.20 (!CS), U19.13 (I), U20.8 (O)
!CLR: U2.10 (SCL), U3.10 (SCL), U13.11 (O), U17.9 (CLR)
!CRES: U11.6 (O)
!CSET: U13.8 (O)
!F: U11.3 (I0), U11.12 (O)
!IE: U22.13 (G)
!JMP: U19.11 (I), U23.1 (1G), U28.13 (I1)
!LOAD: J7.6, U4.1 (SH/!LD), U5.1 (SH/!LD), U16.13 (CLR)
!OE: J2.13, U18.22 (!OE), U20.3 (O)
!PC_EN: U2.13 (G), U3.13 (G), U26.13 (G), U27.13 (G), X2.2
!QD: U11.10 (I1), U19.4 (O)
!RES: U9.1 (CLR)
!RESC: U16.1 (CLR)
!RESET: U26.10 (SCL), U27.10 (SCL)
!RST: U19.8 (O), U21.1 (CLR), U21.13 (CLR), U22.10 (SCL)
!SETC: U16.4 (PRE)
!SS: U22.12 (RCK), X1.5
!T0: U9.11 (!Q3), U20.1 (I0)
!T1: U7.1 (I0), U9.14 (!Q4)
!T17: J7.8, U2.12 (RCK), U3.12 (RCK), U7.5 (I1), U9.3 (!Q1)
!T18: U9.6 (!Q2)
!WE: J2.8, U17.2 (G1), U17.3 (G2), U18.27 (!WE), U20.6 (O)
!Y0: U10.15 (Y0), U12.5 (I1)
!Y1: U10.14 (Y1), U11.1 (I0), U13.4 (I0)
!Y2: U10.13 (Y2), U11.2 (I1), U13.5 (I1)
!Y3: U10.12 (Y3), U11.13 (I2)
!Y4: U10.11 (Y4)
!Y5: U10.10 (Y5), U12.13 (I1), U13.2 (I1)
!Y6: U10.9 (Y6), U19.1 (I)
!Y7: J4.2, U10.7 (Y7), U12.2 (I1), U15.9 (A)
ALU_CARRY_IN: U14.11 (B4)
ALU_CARRY_OUT: U14.9 (C4), U15.5 (A), U21.12 (D)
ALU_SUM_OUT: U14.10 (S4), U15.2 (A)
AOUT: J7.10, U14.12 (A4), U17.8 (QA*), U24.2 (I)
BCC: U23.7 (1Y), U28.9 (I0), U28.10 (I1)
BOUT: U5.9 (QH)
BOUTH: J7.9, U4.9 (QH), U5.10 (SER), U12.9 (I0), U14.13 (S3), U15.12 (A)
BRANCH/JUMP: J4.1, U28.6 (O)
BUS0: D0.A, D16.A, J1.4, U17.7 (A/QA), U18.11 (I/O0), U22.7 (QH)
BUS1: D1.A, D17.A, J1.3, U17.13 (B/QB), U18.12 (I/O1), U22.6 (QG)
BUS2: D2.A, D18.A, J1.2, U17.6 (C/QC), U18.13 (I/O2), U22.5 (QF)
BUS3: D3.A, D19.A, J2.20, U17.14 (D/QD), U18.15 (I/O3), U22.4 (QE)
BUS4: D4.A, D20.A, J2.19, U17.5 (E/QE), U18.16 (I/O4), U22.3 (QD)
BUS5: D5.A, D21.A, J2.18, U17.15 (F/QF), U18.17 (I/O5), U22.2 (QC)
BUS6: D6.A, D22.A, J2.17, U17.4 (G/QG), U18.18 (I/O6), U22.1 (QB)
BUS7: D7.A, D23.A, J2.16, U17.16 (H/QH), U18.19 (I/O7), U22.15 (QA)
BUS17: U23.2 (B)
CARRY: U21.9 (Q)
CIN: U16.5 (Q)
CLK16: U6.9 (P0)
COUT: U16.2 (D)
CSUP: U11.4 (I1), U13.3 (O)
DB0: J1.5, U1.19 (I/O0), U5.6 (H), U18.10 (A0), U27.7 (QH)
DB1: J1.6, U1.18 (I/O1), U5.5 (G), U18.9 (A1), U27.6 (QG)
DB2: J1.7, U1.17 (I/O2), U5.4 (F), U18.8 (A2), U27.5 (QF)
DB3: J1.8, U1.16 (I/O3), U5.3 (E), U18.7 (A3), U27.4 (QE)
DB4: J1.9, U1.15 (I/O4), U5.14 (D), U18.6 (A4), U27.3 (QD)
DB5: J1.10, U1.14 (I/O5), U5.13 (C), U18.5 (A5), U27.2 (QC)
DB6: J1.11, U1.13 (I/O6), U5.12 (B), U18.4 (A6), U27.1 (QB)
DB7: J1.12, U1.12 (I/O7), U5.11 (A), U18.3 (A7), U27.15 (QA)
DIV_CLK: J20.1, J20.3, J20.5, J20.7, J20.9, J20.11, J20.13, J20.15, J20.17, J20.19, U7.12 (I0), U7.13 (I1), U8.2 (CLK), U9.9 (CLK), U21.3 (CLK), U21.11 (CLK)
FOUT: D8.C, D9.C, J7.11, R9.2, U17.18 (SL)
GATE: U7.3 (O), U7.4 (I0), U7.9 (I0), U8.1 (CLR)
GCLK: J2.7, J7.7, U4.2 (CLK), U5.2 (CLK), U11.8 (O), U16.3 (CLK), U16.11 (CLK), U17.12 (CLK), U22.11 (SCK), X1.4
GND: C1.1, C2.1, C3.1, C4.1, C5.1, C6.1, C7.1, C8.1, C9.1, C10.1, C11.1, C12.1, C13.1, C14.1, C15.1, C16.1, C17.1, C18.1, C19.1, C20.1, C21.1, C22.1, C23.1, C24.1, C25.1, C26.1, C27.1, C28.1, C30.1, C31.1, C32.1, C33.2 (-), J1.1, J3.3, J3.8, J3.13, J3.18, R3.1, R6.1, R7.1, R9.1, RN1.1, RN2.1, RN3.1, S12.1, S13.1, U1.2 (!CE), U1.11 (VSS), U1.20 (!OE), U1.30 (VSS), U2.8 (GND), U3.8 (GND), U4.8 (GND), U4.10 (SER), U4.15 (INH), U5.8 (GND), U5.15 (INH), U6.8 (VSS), U7.7 (GND), U8.8 (GND), U9.8 (GND), U10.4 (G2A), U10.5 (G2B), U10.8 (GND), U11.7 (GND), U12.7 (GND), U13.7 (GND), U14.2 (B2), U14.3 (A2), U14.5 (A1), U14.8 (GND), U15.7 (-UB), U16.7 (GND), U17.10 (GND), U18.14 (VSS), U19.7 (GND), U20.7 (GND), U21.7 (GND), U22.8 (GND), U23.3 (1C3), U23.8 (GND), U23.10 (2C0), U23.11 (2C1), U23.12 (2C2), U23.13 (2C3), U23.15 (2G), U24.1 (OE), U24.7 (GND), U25.7 (GND), U26.8 (GND), U27.8 (GND), U28.7 (GND), U$1.5 (GND), U$1.P$1 (GND), U$1.P$2 (GND), U$1.P$3 (GND), U$1.P$4 (GND), X1.6, X2.6
I0: U15.1 (G)
I1: U13.6 (O), U15.4 (G)
IR0: D13.A, J2.6, U1.10 (I/O8), U4.6 (H), U23.6 (1C0), U25.12 (I), U26.7 (QH)
IR1: D12.A, J1.16, U1.9 (I/O9), U4.5 (G), U23.5 (1C1), U25.9 (I), U26.6 (QG)
IR2: D11.A, J2.5, U1.8 (I/O10), U4.4 (F), U23.4 (1C2), U25.5 (I), U26.5 (QF)
IR3: D10.A, J1.17, U1.7 (I/O11), U4.3 (E), U25.2 (I), U26.4 (QE), U28.2 (I1)
IR4: J2.4, J7.4, U1.6 (I/O12), U4.14 (D), U10.1 (A), U24.12 (I), U26.3 (QD)
IR5: J1.18, J7.3, U1.5 (I/O13), U4.13 (C), U10.2 (B), U24.9 (I), U26.2 (QC)
IR6: J2.3, J7.2, U1.4 (I/O14), U4.12 (B), U10.3 (C), U24.5 (I), U26.1 (QB)
IR7: J1.19, U1.3 (I/O15), U4.11 (A), U24.4 (OE), U24.10 (OE), U24.13 (OE), U25.1 (OE), U25.4 (OE), U25.10 (OE), U25.13 (OE), U26.15 (QA)
JMP: U19.10 (O), U28.1 (I0)
LD: U13.1 (I0), U13.13 (I1)
LJ: U28.3 (O), U28.4 (I0)
M0: U8.3 (A)
M1: U8.4 (B)
M2: U8.5 (C)
M3: U8.6 (D)
MA8: J2.10, RN1.2, U18.25 (A8), U25.11 (O)
MA9: J2.11, RN1.3, U18.24 (A9), U25.8 (O)
MA10: J2.14, RN1.4, U18.21 (A10), U25.6 (O)
MA11: J2.12, RN1.5, U18.23 (A11), U25.3 (O)
MA12: J1.13, RN1.6, U18.2 (A12), U24.11 (O)
MA13: J2.9, RN1.7, U18.26 (A13), U24.8 (O)
MA14: J1.14, RN1.8, U18.1 (A14), U24.6 (O)
MA15: RN1.9
MISO: U22.14 (SER), X1.3
MOSI: U24.3 (O), X1.2
unnamed: D0.K (C), RN2.2
unnamed: D1.K (C), RN2.3
unnamed: U28.5 (I1), U28.11 (O)
unnamed: U7.10 (I1), U7.11 (O)
unnamed: D2.K (C), RN2.4
unnamed: D8.A, U15.3 (Y)
unnamed: R4.1, S12.3 (2)
unnamed: C32.2, R5.1, S13.3 (2), U19.5 (I)
unnamed: POWER.K (C), R7.2
unnamed: U12.8 (O), U14.14 (A3)
unnamed: D9.A, U15.6 (Y)
unnamed: D3.K (C), RN2.5
unnamed: D4.K (C), RN3.2
unnamed: D5.K (C), RN3.3
unnamed: D6.K (C), RN3.4
unnamed: D7.K (C), RN3.5
unnamed: U2.9 (QH*), U3.14 (SER)
unnamed: U26.9 (QH*), U27.14 (SER)
unnamed: U12.3 (O), U15.13 (G)
unnamed: C30.2, Q1.2, R1.1
OSC10: R1.2, R2.1, U6.10 (!P0)
OSC11: C31.2, Q1.1, R2.2, U6.11 (P1)
PC_CARRY_IN: U14.7 (C0), U16.9 (Q)
PC_CARRY_OUT: U14.1 (S2), U16.12 (D)
PC_CLK: J1.15, U2.11 (SCK), U3.11 (SCK), U7.8 (O), U11.11 (I2)
PC_IN: J7.5, U2.14 (SER), U15.8 (Y), U15.11 (Y)
PC_SUM: U14.4 (S1), U15.10 (G)
PC_SUM_IN: U14.6 (B1)
PC_SUM_OUT: J7.1, U3.9 (QH*), U27.9 (QH*)
QD: U8.11 (QD), U19.3 (I)
RCO: U8.15 (RCO), U9.4 (D1)
RESET: U6.12 (RES), U19.6 (O), U19.9 (I)
RMA0: J3.20, J4.10, U1.21 (A0), U3.7 (QH)
RMA1: J3.19, J4.9, U1.22 (A1), U3.6 (QG)
RMA2: J3.17, J4.8, U1.23 (A2), U3.5 (QF)
RMA3: J3.16, J4.7, U1.24 (A3), U3.4 (QE)
RMA4: J3.15, J4.6, U1.25 (A4), U3.3 (QD)
RMA5: J3.14, J4.5, U1.26 (A5), U3.2 (QC)
RMA6: J3.12, J4.4, U1.27 (A6), U3.1 (QB)
RMA7: J3.11, J4.3, U1.28 (A7), U3.15 (QA)
RMA8: J3.10, U1.29 (A8), U2.7 (QH)
RMA9: J3.9, U1.31 (A9), U2.6 (QG)
RMA10: J3.7, U1.32 (A10), U2.5 (QF)
RMA11: J3.6, U1.33 (A11), U2.4 (QE)
RMA12: J3.5, U1.34 (A12), U2.3 (QD)
RMA13: J3.4, U1.35 (A13), U2.2 (QC)
RMA14: J3.2, U1.36 (A14), U2.1 (QB)
RMA15: J3.1, U1.37 (A15), U2.15 (QA)
RUN: U9.12 (D3)
S0: U17.1 (S0), U19.12 (O)
S1: R8.2, U17.19 (S1)
SER_CLK: U26.11 (SCK), U27.11 (SCK), X2.4
SER_IN: U26.14 (SER), X2.3
SETC: U13.10 (I1)
STB: U26.12 (RCK), U27.12 (RCK), X2.5
T0: U9.10 (Q3), U9.13 (D4)
T1: U9.15 (Q4), U20.9 (I0)
T17: U9.2 (Q1), U9.5 (D2), U20.4 (I0)
T18: U9.7 (Q2)
VCC: C1.2, C2.2, C3.2, C4.2, C5.2, C6.2, C7.2, C8.2, C9.2, C10.2, C11.2, C12.2, C13.2, C14.2, C15.2, C16.2, C17.2, C18.2, C19.2, C20.2, C21.2, C22.2, C23.2, C24.2, C25.2, C26.2, C27.2, C28.2, C33.1 (+), J2.1, POWER.A, R4.2, R5.2, R8.1, U1.1 (VPP), U1.40 (VCC), U2.16 (VCC), U3.16 (VCC), U4.16 (VCC), U5.16 (VCC), U6.16 (VDD), U7.14 (VCC), U8.7 (ENP), U8.9 (LD), U8.10 (ENT), U8.16 (VCC), U9.16 (VCC), U10.6 (G1), U10.16 (VCC), U11.5 (I2), U11.9 (I0), U11.14 (VCC), U12.1 (I0), U12.4 (I0), U12.12 (I0), U12.14 (VCC), U13.14 (VCC), U14.15 (B3), U14.16 (VCC), U15.14 (+UB), U16.10 (PRE), U16.14 (VCC), U17.20 (VCC), U18.28 (VCC), U19.14 (VCC), U20.14 (VCC), U21.4 (PRE), U21.10 (PRE), U21.14 (VCC), U22.16 (VCC), U23.16 (VCC), U24.14 (VCC), U25.14 (VCC), U26.16 (VCC), U27.16 (VCC), U28.14 (VCC), U$1.1 (VCC), X1.1, X2.1
Y0: U13.12 (I0), U20.2 (I1), U20.10 (I1)
Y6: U19.2 (O), U20.5 (I1)
ZERO: U21.5 (Q)
ZEROPAGE: D10.C, D11.C, D12.C, D13.C, R6.2
ZIN: D16.C, D17.C, D18.C, D19.C, D20.C, D21.C, D22.C, D23.C, J7.12, R3.2, U20.12 (I0), U20.13 (I1)
ZOUT: U20.11 (O), U21.2 (D), U23.14 (A)

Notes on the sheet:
ALU and PC Incrementer
CLOCK SEQUENCER AND TIMING PULSE GENERATOR
CRYSTAL OSCILLATOR
ZERO & CARRY FLAGS
INSTRUCTION DECODER & CONTROL UNIT
ROM EMULATOR / GPIO UNIT
PROGRAM ROM
ACCUMULATOR
16-BIT B REGISTER
PROGRAM COUNTER
ROMULATOR
JUMP LOGIC

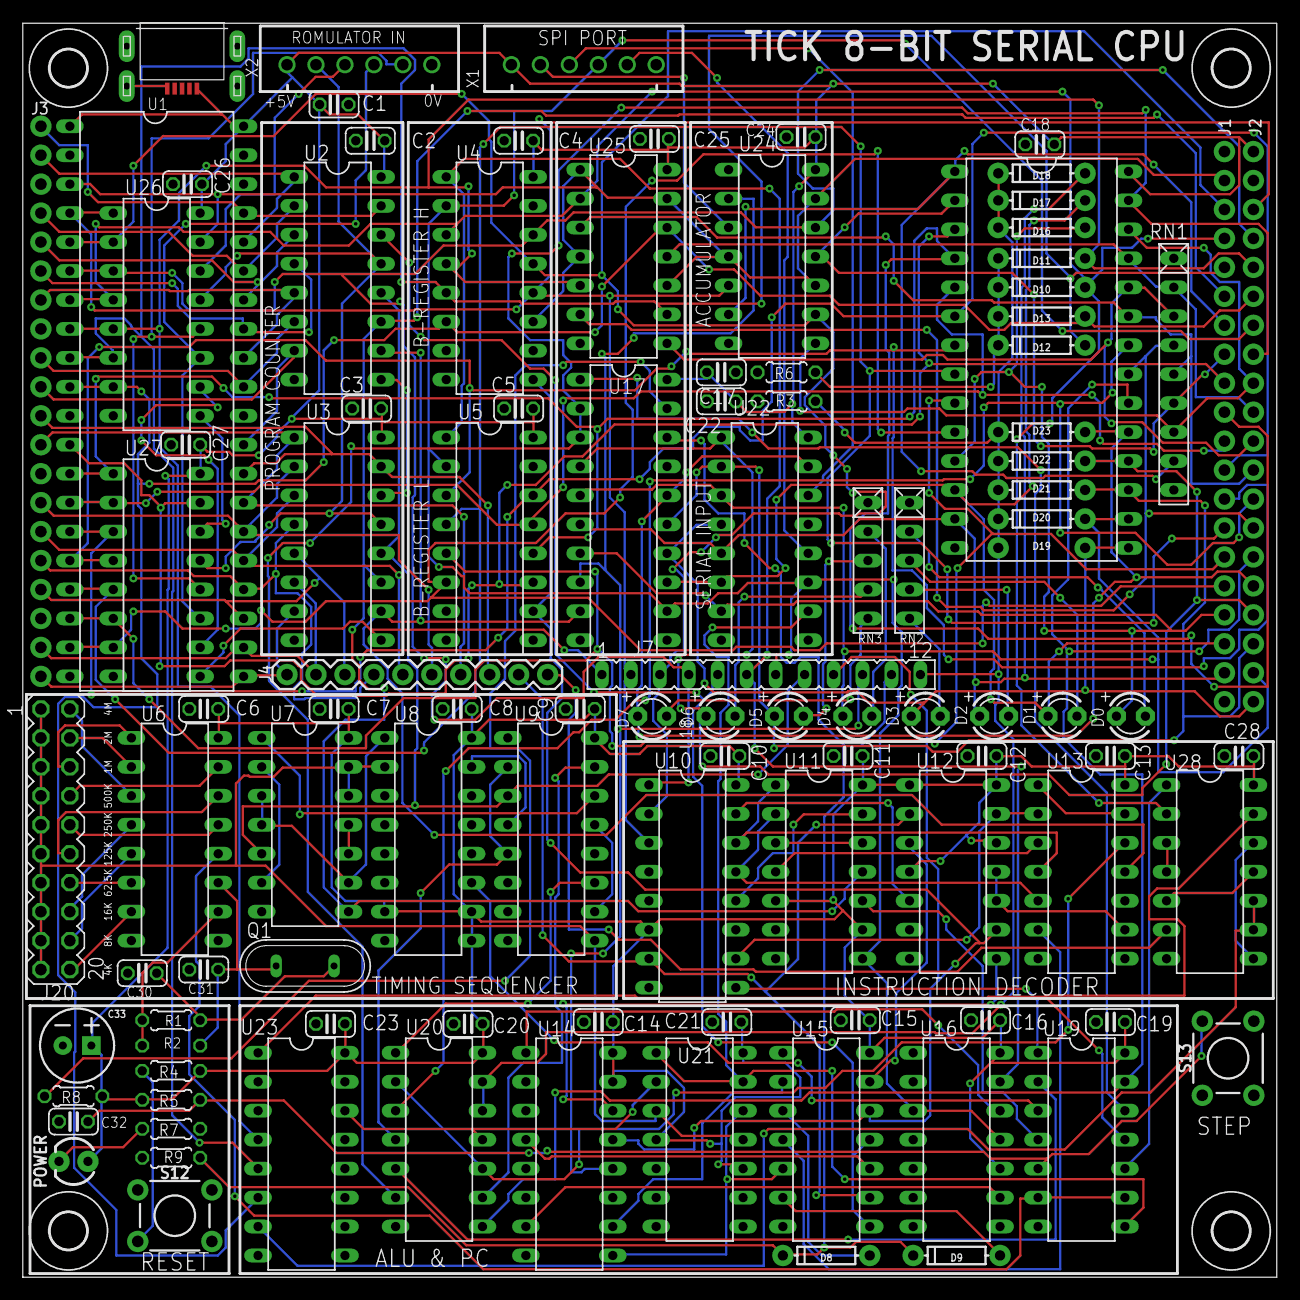
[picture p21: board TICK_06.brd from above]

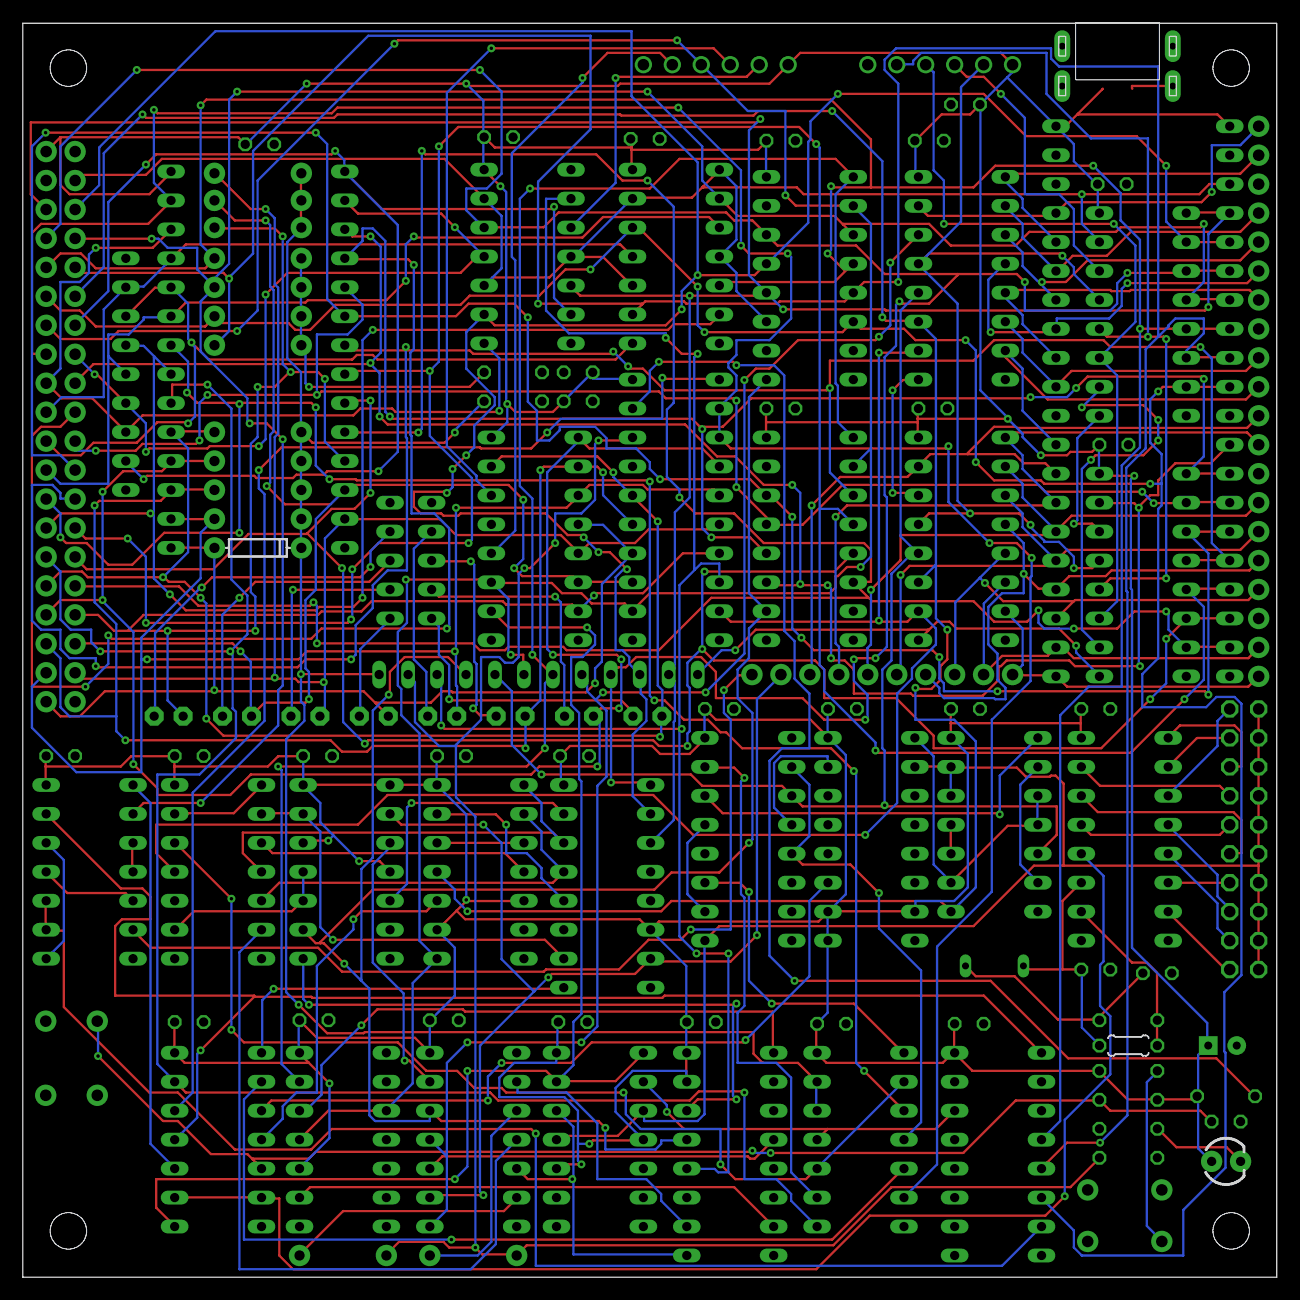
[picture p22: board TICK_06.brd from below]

Board: 4 copper layers, 110.0 x 110.0 mm, 111 parts (2 on the bottom side), 145 nets.

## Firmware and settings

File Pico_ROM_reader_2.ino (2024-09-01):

// This was initially written to drive a "LED and KEY" module - which uses the TM1638 IC
// to multiplex 8, 7-segment displays, 8 single LEDs and 8 push switches
// see https://www.arduino.cc/reference/en/libraries/tm16xx-leds-and-buttons/  for library details

// LED & KEY module https://www.aliexpress.com/item/1005004919749417.html

// LED & KEY code commented out here  - now just reports to serial terminal with print statements

// #include <TM1638plus.h>

  
int d4096 = 0;
int d256 = 0;
int d16 = 0;
int d0  = 0;

/*
// GPIO I/O pins on the Arduino connected to strobe, clock, data,
//pick on any I/O you want.
#define  STROBE_TM 27 // strobe = GPIO connected to strobe line of module
#define  CLOCK_TM 28  // clock = GPIO connected to clock line of module
#define  DIO_TM 29 // data = GPIO connected to data line of module
bool high_freq = false; //default false,, If using a high freq CPU > ~100 MHZ set to true.

//Constructor object (GPIO STB , GPIO CLOCK , GPIO DIO, use high freq MCU)
TM1638plus tm(STROBE_TM, CLOCK_TM , DIO_TM, high_freq);
int i= 0;


int digit0 = 0;
int digit1 = 0;
int digit2 = 0;
int digit3 = 0;


// Some vars and defines for the tests.
#define myTestDelay 100

void Test0()
{
  // Test 0 reset test
  tm.setLED(0, 1);
  delay(myTestDelay);
  tm.reset();
}


void DisplayHexAddress() {
   tm.brightness(7);
  


  d4096 = i/4096;
  d256 =  (i-(4096 *d4096))/256;
  d16  =  (i-((4096 *d4096)+(256*d256)))/16;
  d0   =  i-(((4096 *d4096)+(256*d256)+(16*d16)));


  tm.displayHex(0, d4096);
  tm.displayHex(1, d256);
  tm.displayHex(2, d16);
  tm.displayHex(3, d0);

 
  delay(100);
 

  i++;

}

/*

void Test13()
{
  //Test 13 LED display
  uint8_t LEDposition = 0;

  // Test 13A Turn on redleds one by one, left to right, with setLED where 0 is L1 and 7 is L8 (L8 RHS of display)
  for (LEDposition = 0; LEDposition < 8; LEDposition++) {
    tm.setLED(LEDposition, 1);
    delay(500);
    tm.setLED(LEDposition, 0);
  }

  // TEST 13b test setLEDs function (0xLEDXX) ( L8-L1 , XX )
  // NOTE passed L8-L1 and on display L8 is on right hand side. i.e. 0x01 turns on L1. LXXX XXXX
  // For model 1 just use upper byte , lower byte is is used by model3 for bi-color leds leave at 0x00 for model 1.
  tm.setLEDs(0xFF00); //  all LEDs on
  delay(myTestDelay3);
   tm.setLEDs(0x0100); // Displays as LXXX XXXX (L1-L8) , NOTE on display L8 is on right hand side.
  delay(myTestDelay3);
  tm.setLEDs(0xF000); //  Displays as XXXX LLLL (L1-L8) , NOTE on display L8 is on right hand side.
  delay(myTestDelay3);
  tm.setLEDs(0x0000); // all off
  delay(myTestDelay3);

}


  //Test 14 buttons and LED test, press switch number S-X to turn on LED-X, where x is 1-8.
  //The HEx value of switch is also sent to Serial port.
  tm.displayText("buttons ");
  delay(myTestDelay3);
  

  void Buttons() {
  while (1) // Loop here forever
  {
    uint8_t buttons = tm.readButtons();
       buttons contains a byte with values of button s8s7s6s5s4s3s2s1
       HEX  :  Switch no : Binary
       0x01 : S1 Pressed  0000 0001
       0x02 : S2 Pressed  0000 0010
       0x04 : S3 Pressed  0000 0100
       0x08 : S4 Pressed  0000 1000
       0x10 : S5 Pressed  0001 0000
       0x20 : S6 Pressed  0010 0000
       0x40 : S7 Pressed  0100 0000
       0x80 : S8 Pressed  1000 0000
      
    Serial.println(buttons, HEX);
    doLEDs(buttons);
    tm.displayIntNum(buttons, true, TMAlignTextLeft);
    delay(250);
  }
}

// scans the individual bits of value sets a LED based on which button pressed
void doLEDs(uint8_t value) {
  for (uint8_t LEDposition = 0; LEDposition < 8; LEDposition++) {
    tm.setLED(LEDposition, value & 1);
    value = value >> 1;
  }
}

*/


  int ROM_address = 0;

  int RM15 = 0;
  int RM14 = 0;
  int RM13 = 0;
  int RM12 = 0;
  int RM11 = 0;
  int RM10 = 0;
  int RM9 = 0;
  int RM8 = 0;
  int RM7 = 0;
  int RM6 = 0;
  int RM5 = 0;
  int RM4 = 0;
  int RM3 = 0;
  int RM2 = 0;
  int RM1 = 0;
  int RM0 = 0;



void setup() {

Serial.begin(115200);

  // initialize digital pins 15:0 as input 
  pinMode(0, INPUT);
  pinMode(1, INPUT);
  pinMode(2, INPUT);
  pinMode(3, INPUT);
  pinMode(4, INPUT);
  pinMode(5, INPUT);
  pinMode(6, INPUT);
  pinMode(7, INPUT);
  pinMode(8, INPUT);
  pinMode(9, INPUT);
  pinMode(10, INPUT);
  pinMode(11, INPUT);
  pinMode(12, INPUT);
  pinMode(13, INPUT);
  pinMode(14, INPUT);
  pinMode(15, INPUT);

   
  // Test 0 reset
  // Test0();


}

// the loop function runs over and over again forever
void loop() {

    RM15 = digitalRead(0);
    RM14 = digitalRead(1);
    RM13 = digitalRead(2);
    RM12 = digitalRead(3);
    RM11 = digitalRead(3);
    RM10 = digitalRead(5);
    RM9 = digitalRead(6);
    RM8 = digitalRead(7);
    RM7 = digitalRead(8);
    RM6 = digitalRead(9);
    RM5 = digitalRead(10);
    RM4 = digitalRead(11);
    RM3 = digitalRead(12);
    RM2 = digitalRead(13);
    RM1 = digitalRead(14);
    RM0 = digitalRead(15);
  ROM_address = ((32768 * RM15)+(16384 * RM14)+(8192 * RM13)+(4096 * RM12)+(2048 * RM11)+(1024 * RM10)+(512 * RM9)+(256 * RM8)+(128 * RM7)+(64 * RM6)+(32* RM5)+(16 * RM4)+(8 * RM3)+(4 * RM2)+(2 * RM1)+(1 * RM0)); 
    ;
    Serial.print(millis());
    Serial.print("   ");
    Serial.println(ROM_address); 


/*
  tm.brightness(7);
  i = ROM_address;


  d4096 = i/4096;
  d256 =  (i-(4096 *d4096))/256;
  d16  =  (i-((4096 *d4096)+(256*d256)))/16;
  d0   =  i-(((4096 *d4096)+(256*d256)+(16*d16)));

  tm.displayHex(0, d4096);
  tm.displayHex(1, d256);
  tm.displayHex(2, d16);
  tm.displayHex(3, d0);

  */


  delay(100);
}

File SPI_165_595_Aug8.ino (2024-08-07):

#include <SPI.h>
/* Use pin9 to latch 165 data
use pin10 to latch 595 data
connect SCK (d13) to all clock lines
connect MISO (d12) to 165 data out
connect MOSI (d11) to 595 data in */
byte byte1 ;
byte byte2 ;
void setup(){
SPI.begin(); // default speed 4 MHz
pinMode(9,OUTPUT);
pinMode(10,OUTPUT);}
void loop(){
digitalWrite (9, LOW);
digitalWrite (9, HIGH); // capture 165 inputs
byte1 = SPI.transfer(0); // read in 165 #2 data
byte2 = SPI.transfer(0); // read in 165 #1 data
SPI.transfer(byte1); // send data to 595 #1
SPI.transfer(byte2); // send data to 595 #2
digitalWrite (10, LOW);
delayMicroseconds(10);
digitalWrite (10, HIGH); // latch to output of 595s.
}

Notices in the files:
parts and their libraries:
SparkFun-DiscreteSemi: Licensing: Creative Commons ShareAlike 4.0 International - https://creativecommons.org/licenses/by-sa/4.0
